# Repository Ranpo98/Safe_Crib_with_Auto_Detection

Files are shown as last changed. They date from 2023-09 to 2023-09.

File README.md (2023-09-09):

# Safe Crib With Auto Hazard-Detection

## Project Overview

**Duration**: December 2022 – May 2023

The "Safe Crib With Auto Hazard-Detection" is an innovative project aimed at utilizing technology to enhance the safety of infants while in their cribs. The project focuses on developing a system that employs various sensor arrays to monitor the baby's movements and posture in the crib, alerting caregivers to potential unintentional falls and other hazards. 

## Features and Achievements

- Utilization of various sensor arrays to closely monitor baby's movements and posture within the crib, providing alerts for unintentional falls.
- Independent PCB design, forming the central control hub for the sensor array and a Bluetooth module facilitating data transmission.
- Simulation and testing of PCB conditions with extensive sensor arrays connected, using Kicad and Cadence® Virtuoso®.
- Prototyping and real-situation sensor accuracy testing with the aid of a breadboard and a crib model crafted with machine tools.
- Implementation of Arduino IDE encoder to program the receiving PCB, and store the predetermined method for decoding transmitted bit signals.
- Nominated for a showcase during the Senior Project design and approval stage, securing a full score in the evaluation phase.

## Technologies Used

- Sensor Arrays
- Bluetooth Module
- Kicad
- Cadence® Virtuoso®
- Arduino IDE

## Repository Contents

In this repository, you will find all the files generated throughout the project's progression.

### ⚠️ License & Usage

Please note that unauthorized use of any files or code found within this repository without explicit permission is strictly prohibited.

## Getting Started

To delve deeper into the project details, navigate through the repository. Inside, you will find a rich collection of files, including but not limited to:

- Circuit Designs
- Code Files
- Sensor Calibration Data
- Prototyping Images and Videos

## Conclusion

This project stands as a testament to the fusion of technology and child safety, embodying innovation and dedication.

Thank you for visiting the "Safe Crib With Auto Hazard-Detection" project repository!

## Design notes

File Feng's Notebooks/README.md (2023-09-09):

# ECE 445 Lab Notebook

## 02/10

### Pressure and Sound Sensor 
We carefully considered various options for each subsystem and determined that our pressure sensors should withstand a maximum force of approximately 50 N. After thorough research, we ultimately chose the SEN0294 pressure sensor due to its ability to measure up to 60 N of force. Our team deliberated extensively over which sound sensor to use, as we wanted to select one with a sound pressure level threshold as close to 110 dB as possible.

## Ultrasonic Sensor 
HC-SR04 and HC-SR05 are both designed for distance measurement. However, they are a bit differ in aspects such as operating frequency, which makes the difference in accuracy and response time. Compared to HC-SR05, HC-SR04 operates at a higher frequency of 40kHz, providing higher accuracy. Additionally, HC-SR04 has a shorter response time and can complete a operating cycle in 10 microseconds, while HC-SR05 requires around 58 milliseconds. 

## 02/15

## Connection to Program the Board
I read the document of ATMega328P(https://www.farnell.com/datasheets/74880.pdf). It is wise to use SPI for programming interface. ATMega328P is an 8-bit microcontroller widely used in embedded systems. Through the SPI interface, it can communicate with other devices, such as sensors and displays. The SPI interface uses four signal lines, namely MOSI (Master Output Slave Input), MISO (Master Input Slave Output), SCK (Clock), and CS (Chip Select). In ATMega328P, MOSI and MISO correspond to the output and input data pins. Besides, SCK provides the clock signal, and CS helps select the communication device. 

## 02/17

## Connection to Program the Board (Continue)
After carefully reading the document, I determine to use the interface protocol UART, which uses two signal lines, TX (Transmit) and RX (Receive) for serial communication. In ATMega328P, TX and RX correspond to the output and input data pins. 

## 02/18

## MCU Choice + Pin Connection Check
1. How the output of the sensor be suitable for the MCU? Voltage range? Duration?
2. What are the appropriate resistor/capacitor? Tolerance range
3. What is the clock cycle to burn the code onto the board?   

## Completion progress: 
1. Used the SPI interface to program.
2. Specified the wanted PCB must have MOSI, MISO, and SCK function. ATMega328P fits our requirement. Link of datasheet: https://content.arduino.cc/assets/Atmel-7810-Automotive-Microcontrollers-ATmega328P_Datasheet.pdf
3. The operating voltage range: 2.6 V (±0.1V) to 5.4 V (±0.1V)
4. The operating frequency for ATmega328 is 8MHz, which is acceptable for this project. 

## 02/19

## Team Contract(Responsible for the primary drafting of this document)
Our team determine to keep effective communication and collaboration to maintain a good track on the project for the final success. We have set up regular meetings every Monday afternoon and plan other meetings flexibly based on our progress. During these meetings, we will discuss specific tasks and deadlines, share progress updates, and offer feedback to each other.

Moreover, we have established a public document to keep track of our schedules, tasks, and progress. This document helps us to stay organized and open to ideas and ensures that everyone is on the same page. If a member needs assistance or is facing any difficulties,  we can discuss and solve any issues together. Our goal is to work cohesively and efficiently while supporting and encouraging each other throughout the process.      

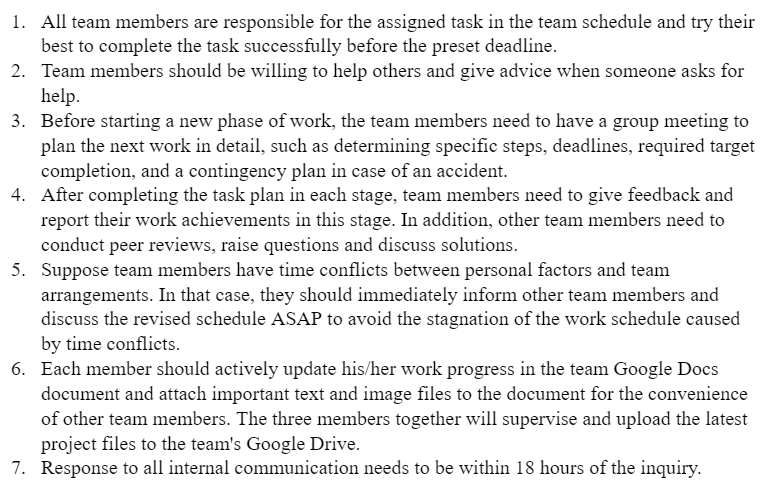
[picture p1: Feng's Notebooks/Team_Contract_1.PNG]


## 02/23

## Reading the SPI Protocol Documents
I looked over some websites and Youtube videos to learn about AVR microcontrollers and the SPI communication protocol.

1. Basic concepts of the SPI communication protocol: SPI (Serial Peripheral Interface) is a serial communication protocol used for communication between microcontrollers and external devices.
2. The master-slave device concept in SPI: The SPI communication protocol has one master device and one or more slave devices, with the master device responsible for controlling the communication process.
3. Four signal lines of SPI: MOSI (Master Out Slave In), MISO (Master In Slave Out), SCK (Serial Clock), and SS (Slave Select).
4. AVR microcontroller's SPI module: Learn how the AVR microcontroller implements SPI communication functions and understand the roles and configuration methods of its internal registers.
5. Example codes for SPI communication, including configuring SPI registers and methods for sending and receiving data.

## 02/27

## PCB Sensor Modification
I redesigned the arrangement of 15 pressure sensors on the PCB. I designed that the 15 sensors would be arranged in three rows and five columns. Within the same row, each column would be connected in parallel and then each one will also be connected in series to a resistor to ensure that there is no excessive current flow, which may cause a short circuit. Additionally, the five sensors in each row would be connected in series with an NMOS to control the switch for the pressure sensor measurement function. By doing this, we can reduce the number of analog pins required on the MCU.

(Updated on 4/26) We have considered the impact of the high-frequency switching signal caused by the NMOS on the low-frequency signal of the pressure sensor itself. However, in the actual verification process, the interference was not significant, so it is within an acceptable range.

## Tips
It should be noted that the logic of these NMOS is to read the readings of all sensors in the array at high. Therefore, the readings of five sensors in each row will be read at the same time. Therefore, it is necessary to carefully read the data in the right order to avoid recording wrong sensor data.         

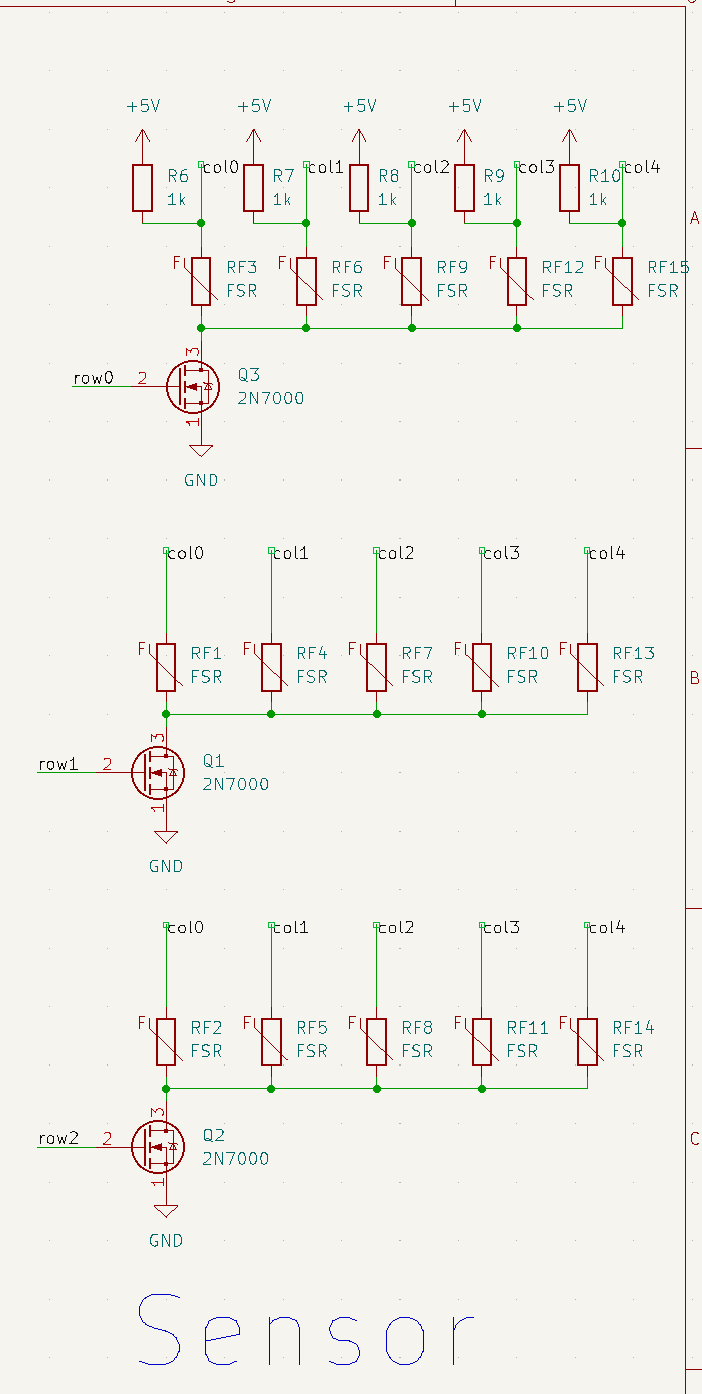
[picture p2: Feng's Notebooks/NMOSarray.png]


## 03/03

## Prototype Sensors On Breadboard (Pressure Sensor in 3*3)

This week, I received the first batch of pressure sensors and began conducting related tests on a breadboard. Since there were less than 15 sensors, I temporarily set up a small-scale test with a 3x3 grid. I connected the pressure sensors to the Arduino Uno according to the PCB schematic and attempted to apply pressure to multiple sensors simultaneously to observe the readings reflected in the Arduino IDE terminal. Meanwhile, I also started writing code for the pressure sensor data evaluation, allowing the MCU to print a preset alarm message when it detects more than 5N of force on multiple pressure sensors simultaneously. The result was that the prototype successfully achieved the desired outcome during the small-scale breadboarding test.

## 03/06

## Prototype Sensors On Breadboard (Add Ultrasonic Sensor) 
I plan to complete the Pressure Sensor, Ultrasounic Sensor, and Sound Sensor prototyping, splice the basic circuit on the breadboard, and code corresponding driver on the Arduino IDE.

For the pressure Sensor, the increase of pressure will lead to the decrease of resistance, so it is quantified as a value in the range of 1-1024 in IDE. By building a 3*5 matrix, we add judgment statements. Every time the value of a sensor in the matrix changes to a value less than 900 after each loop delay, the count increments by 1. Then, if the current count value is greater than 4, it can be used to judge that the baby is crawling. For ultrasounic Sensor, I let the program detect the difference between the two return times of echopin, multiply by the speed of the sound and divide by two to get the distance data. Finally, whether the distance is less than the length of crib is detected to determine whether the baby triggers the alarm. The sound sensor returns a voltage data, so I wrote the code to detect and calculate the difference of it between loops and match that to the range between 1-1024, the higher than volume is, the larger the value is. Once the value is higher than 58, it will set a preset variable to true and trigger the alarm.

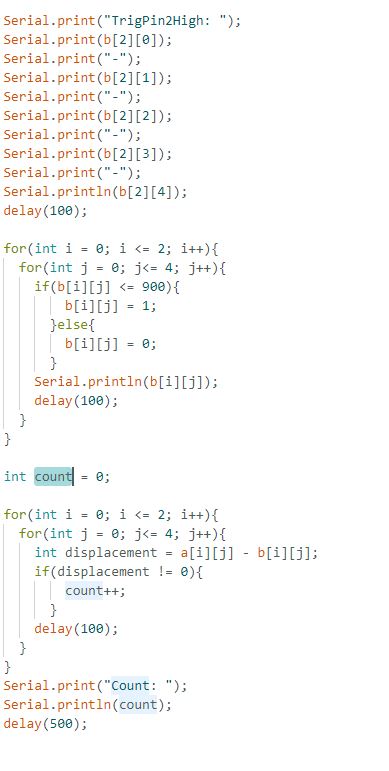
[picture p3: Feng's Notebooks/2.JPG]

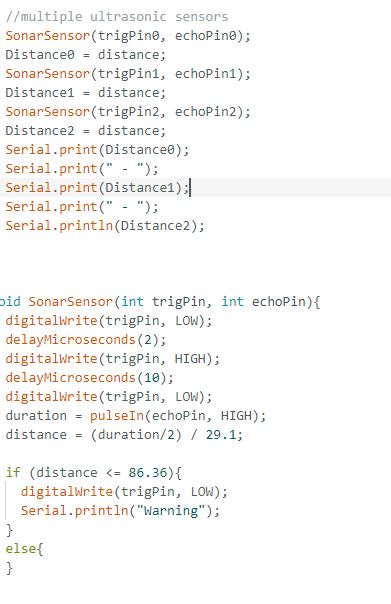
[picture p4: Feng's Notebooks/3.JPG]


## 03/13

## Preliminary Setup of the Pressure Sensor on the Breadboard
I preliminarily completed the layout and wiring of the pressure sensor on the breadboard and conducted an initial test by connecting it to the Arduino UNO. It was verified that the pressure sensor could successfully measure results. However, there were still some issues. As the individual pressure sensor was a thin sheet, its sensitivity to pressure changes was compromised due to its thinness and the pressure applied on it being dispersed by the tabletop it was on.

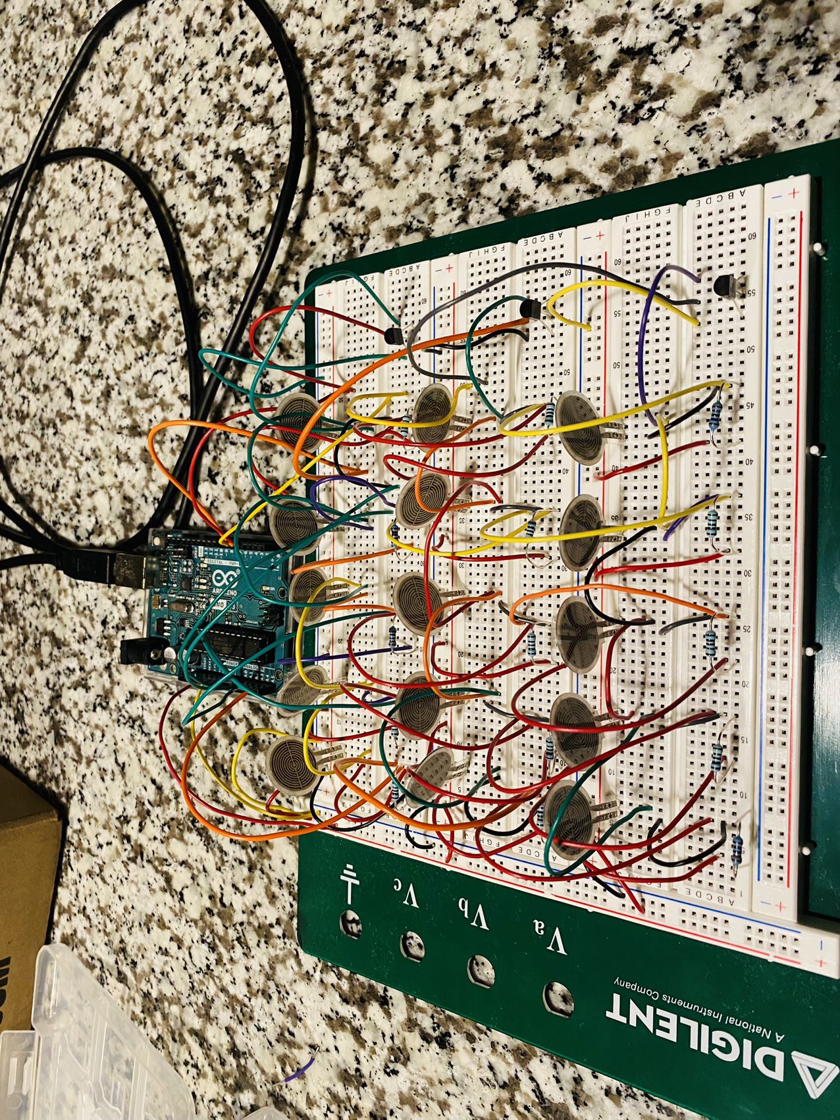
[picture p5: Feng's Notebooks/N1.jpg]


## 03/16

## Preliminary Setup of the Ultrasonic Sensor on the Breadboard
I conducted testing on the ultrasonic sensor, and it was detected that due to the HC-SR04's Effectual Angle being approximately 15 degrees, caution needs to be taken when arranging the sensors to ensure they are not too close together. Additionally, I also observed some strange phenomena, where obstruction in front of the ultrasonic sensor in position 4 would trigger an alarm in position 2. Furthermore, sometimes, the alarm trigger probability is unstable when an object is placed at the threshold distance set in the program. I believe this is due to the microphone of the sensor emitting sound waves that are too scattered.

## 03/20

## Integrate Sensors Prototype
I have started and complete partially on the integration of the Sensor Prototype. I want to test whether the program can simultaneously process the input data of multiple sensors. Also use a 3-bit array to represent all eight cases, including the trigger/not trigger cases for three sensors. It makes convenience for the data transmission through Bluetooth later in the project. 

I asked the program to output a variable for each sensor based on the trigger criteria we previously set for each sensor. If the corresponding condition is triggered, bitSet the value to 1, otherwise bitClear the value back to zero. Each sensor occupies one bit of code, so the three sensors correspond to three bits of code, which are 2\*2\*2 = 8 cases in total. Therefore, the receiving end can recognize the corresponding case after receiving the Bluetooth signal.

| Ultrasonic | Pressure | Sound | Readings |
| ---| ---| ---| ---|
| 0 | 0 | 0 | Read as case 0 |
| 1 | 0 | 0 | Read as case 1 |
| 0 | 1 | 0 | Read as case 2 |
| 1 | 1 | 0 | Read as case 3 |
| 0 | 0 | 1 | Read as case 4 |
| 1 | 0 | 1 | Read as case 5 |
| 0 | 1 | 1 | Read as case 6 | 
| 1 | 1 | 1 | Read as case 7 |

## 03/25

## Modification on Crib Model -- Large Paper Box
I made some modifications to the crib model, which is a paper box that fits the dimensions described in our design document. In order to ensure that the ultrasonic sensor array can cover all areas of the short side of the crib, I reduced the distance between the two middle sensors from 15cm to 10cm, which ensured full coverage of the scan, and duplicate areas will obtain data from two sensors that can be used to verify the data.

I cut the paper box according to the style of the baby crib, cut off the top surface, and then taped one of the openings on both sides, leaving the other opening for easy installation of the pressure sensor matrix and necessary adjustments. Then, together with Yuhao, we accurately marked the installation positions of each pressure sensor on the bottom edge of the paper box, for easy installation later. I also marked the installation positions of the subsequent circuit case and ultrasonic sensors on the outer wall of the paper box.

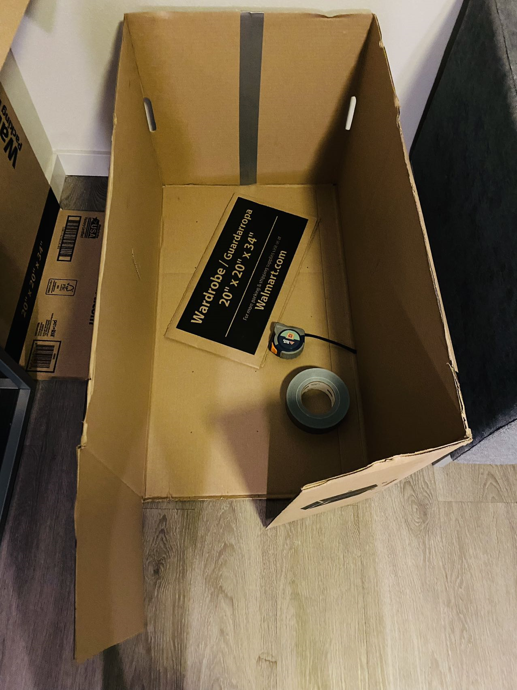
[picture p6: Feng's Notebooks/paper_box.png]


## Issue on Sound Sensor
Upon testing the sound sensor, we discovered some unexpected issues. When there is no noise in the nearby environment, the digital output continuously returns a value of "1," and the analog output returns around 60. We have identified this as a malfunction in the sensor. We may need to buy a brand-new sound sensor or adjust the if statement in the code. 

## 03/28

## Installation of Pressure Sensor & Crib Surface Polishing  
Since Dushyant did not know we had two PCBs, the timing of the order was delayed. As a result, we cannot perform soldering on the crib PCB at this stage. Therefore, I decided to start building our crib model, which is the cardboard box previously mentioned. To address the sensitivity issue with the pressure sensor mentioned before, and combining with Xinlong's idea, we obtained 15 cylindrical pieces of wood from the machine shop, each with a height of 10mm, a diameter of 16mm, and a total weight-bearing capacity of at least 6.8Kg. I attached these cylindrical pieces to the plastic film surface of the pressure sensor with double-sided tape, making them at a different height level from the crib's bottom cardboard. Therefore, the force applied on the objects above would be mainly concentrated on the plane of the cylindrical pieces, thereby transmitting the force to the pressure sensor and enhancing its sensitivity during actual operation. I plan to complete the bottom wiring and the wooden cylinder attachement of the pressure sensor within four days, as well as cut the box to make it closer to the shape of a real crib. Additionally, I adjusted the installation position of the ultrasonic sensor, added a back panel for fixing, and polished and adjusted the cardboard on both sides to ensure that there are no overly uneven parts.

As we are still testing the ultrasonic sensor on the breadboard and Xinlong wants to use this opportunity to test the monitor subsystem, I plan to install the remaining two types of sensors onto the crib in one week.

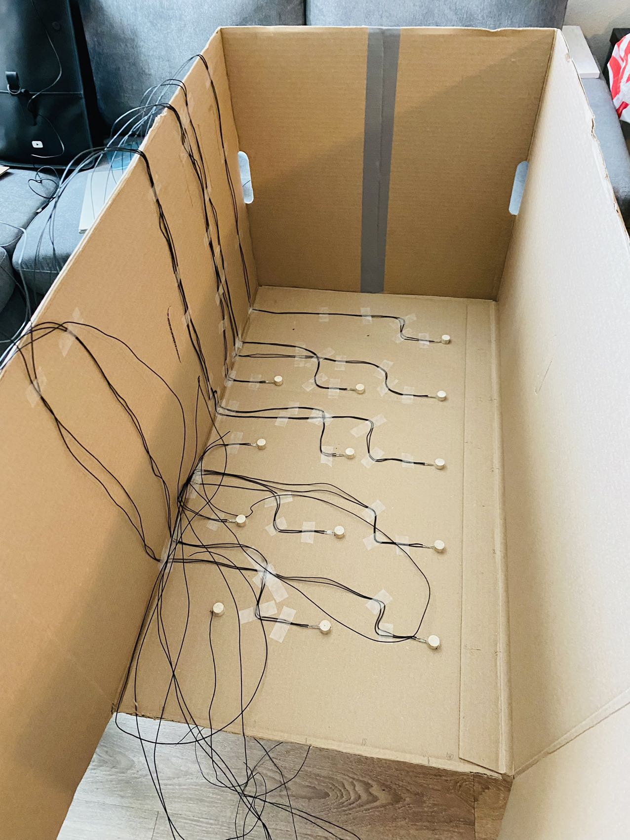
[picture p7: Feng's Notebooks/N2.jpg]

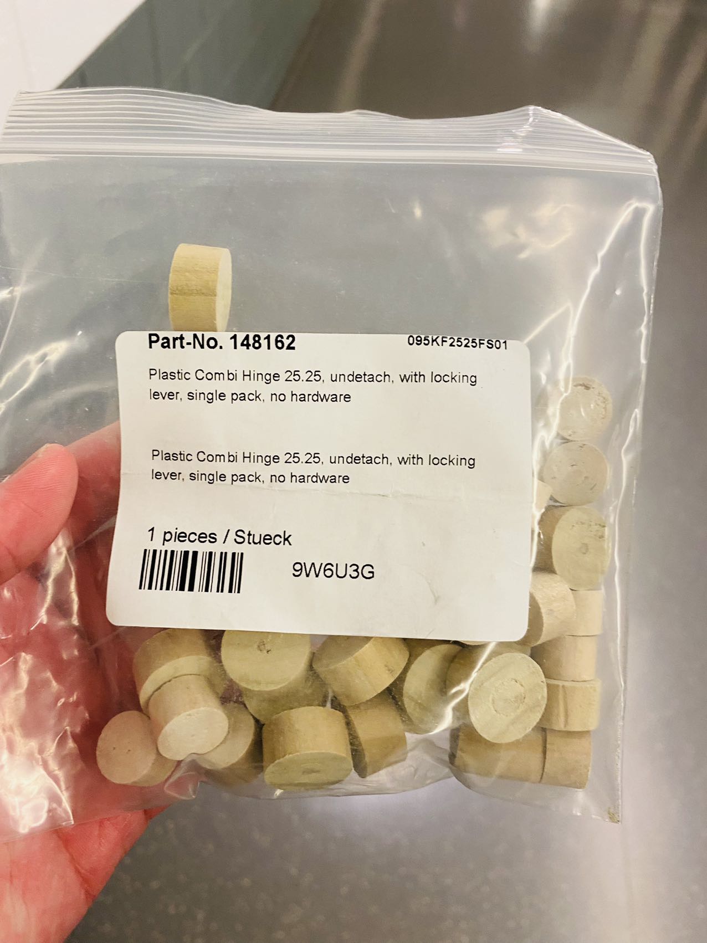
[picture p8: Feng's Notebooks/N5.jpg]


## 04/03

## Modification and Testing on the Bluetooth Data Transmission
After setting up all of the sensors, we performed a Bluetooth connection and communication test to confirm that the system could effectively collect and analyze data, and transmit information via Bluetooth. Following Xinlong's recommendation, we attempted to have the MCU and Bluetooth module send signals, containing a single letter from A to Z in each loop, transmitted in order. All of the packages were ultimately received successfully. Next, the two systems were tested by transmitting the analyzed byte information to the receiving end, where it was successfully printed on the display. We also tested the triggering of each sensor and arranged them in various combinations, with most combinations successfully displaying the corresponding text on the receiving end and triggering the corresponding buzzer.

However, it should be noted that during our testing of the pressure sensor, its performance was slightly subpar. The display often did not show any text, indicating that the alarm was either not sent via Bluetooth or was not triggered due to a mismatch in communication refresh cycles between the two systems. We reduced some of the delays and the threshold of the pressure sensor in the program, which resulted in a slight improvement, but further improvement is still needed.

## Not Showing "Crib signal not found" on Display
We have rectified a software glitch that prevented the "Crib signal not found" notification from appearing on the screen when there was no signal received from the Bluetooth. This issue is caused by an AND operation (avail_num == 0 && cur_time > last_msg_time + WAIT_MSG_TIME_OUT) in the code. It makes legal action to skip the return statement in the loop. These are the detailed explanantion: 

1. avail_num == 0: This condition checks if the number of available signals (avail_num) is equal to 0. A value of 0 indicates that no signal is being received.
2. cur_time > last_msg_time + WAIT_MSG_TIME_OUT: This condition checks if the current time (cur_time) is greater than the last time a message was received (last_msg_time) plus a predefined waiting timeout duration (WAIT_MSG_TIME_OUT). If the current time exceeds this calculated limit, it means that the maximum allowed time for waiting for a message has been surpassed.

The conditional expression uses a logical AND operator (&&), which requires both conditions to be satisfied in order to return true. If avail_num is 0 (no signal) and the current time has exceeded the allowed waiting time limit, the expression evaluates to true. This typically triggers a subsequent action, such as, in this context, causing the "Crib signal not found" notification to not be displayed when the expression is true. We changed the second statement scope to the subordinary scope of the first statement to fix this issue. 

## Inconsistencies in Pressure Sensor Performance
The pressure sensors are supposed to consistently deliver notifications indicating the baby's movements when any of them detects a change within a certain range. However, in some instances, notifications were triggered during both pressing down and release, while in others, they were only activated during one of the action, not both. There are even cases that no notifications were generated at all, which is in nearly 5% of the time. We initially attempted to rectify the issue by comparing the time difference between two readings, but this approach does not improve much. Likewise, averaging ten readings into a single measurement to avoid interference did not work well. Upon more detailed testing and analyzing, we decided not to care too much on this because the pressure sensor itself works and responds very fast and senstitive to the force change. Approximately 90% of the time, the pressure sensors provide accurate measurement data in a timely manner. 

## 04/06

## All Sensors Extended Lines Soldering
Xinlong and I went to 2070 to perform soldering on the pressure sensor and ultrasonic sensor since the preliminary testing on the breadboard was completed. We needed to add extension wires to connect the sensors to the PCB boxes installed on the cardboard box's sidewall. During the soldering process, we encountered a problem where the pin of the pressure sensor was very thin, resulting in hollow soldering points that would automatically come off after a while. We had to perform additional soldering a few times to fix this issue.

## 04/08

## Crib Physical Structure Build-up
The crib has been built and is considered mostly completed, with all three sets of sensors successfully installed. The pressure sensor is installed at the bottom of the cardboard box, with a layer of plastic film covering it to prevent any risk of electrical shock. On top of the sensor is a layer of mattress. The ultrasonic sensor is first installed on a piece of cardboard, then attached to the short side of the crib with adhesive, ensuring that the sensor is at a height of about 20 inches from the bottom. However, the sound sensor has not been installed yet since it needs to be installed in the crib's PCB box, which has not arrived from the machine shop yet.

I organized and routed the long wires of the pressure sensors according to my pre-planned layout, and then managed the wiring on the side walls of the crib cardboard box. Finally, I bundled the wires on the exterior of the longer side wall. Xinlong mentioned that he wanted to be responsible for connecting the wires to the PCB pins, so I handed that part over to him.

## 04/15

## Ultrasonic Sensor Issue
After installing the four ultrasonic sensors on the crib, we conducted tests on them. However, the results of this on-site test on the crib differed significantly from our previous tests on the breadboard. In simple terms, the sensors became extremely unstable. Sometimes they would trigger an alarm beyond the preset warning distance, while other times they remained unresponsive even when touching the microphone surface. We studied the issue for a long time, adjusted the code parameters, but it does not change its performance much. 

Eventually, we discovered that the ultrasonic sensors on the edges sometimes alarmed for objects placed outside the crib, which meant that the detection range of the ultrasonic waves was broader than we had imagined. A reasonable hypothesis was that the width and length of the microphone surface caused the ultrasonic waves to emit not from a single point, making the sound waves spread wider as they traveled, eventually reflecting off objects outside the originally anticipated range, causing detection errors and false alarms.

To address this issue, we devised a targeted solution. We cut A4 paper into strips, rolled them into tubes, and fitted them onto the ultrasonic sensors, allowing the sound waves emitted from the microphone to propagate through an extended channel. This measure effectively enhanced the directionality of the sound waves, significantly reducing the edge sound wave reflections influenced by surrounding objects, and consequently reducing false alarms and non-alarm occurrences.   

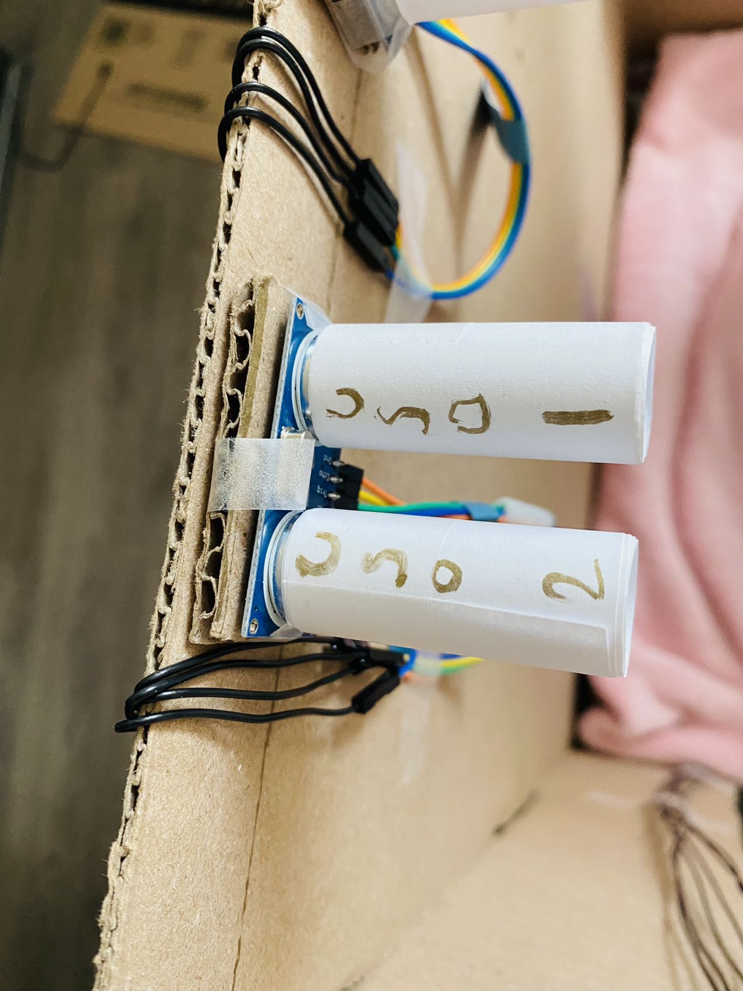
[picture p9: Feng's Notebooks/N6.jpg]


## 04/17

## Ultrasonic Sensor Issue (Continue)
After several days of thinking, I proposed an alternative plan. Since we consider that the measurement errors were caused by the diffusion of ultrasonic waves and the cluttered reflections from the crib's four walls, we could install sound-absorbing materials on the two long sides and one short side to prevent the generation of scattered waves. Ultimately, we purchased dishwashing sponge cloths from the supermarket and placed them on the cardboard walls on all four sides. Due to the abundance of wires on the two long sides, we temporarily decided to apply the sponge cloths only to the opposite short side cardboard wall. The latest results showed an improvement in the performance of the ultrasonic sensors, eliminating most of the previous false alarms and non-alarm occurrences.

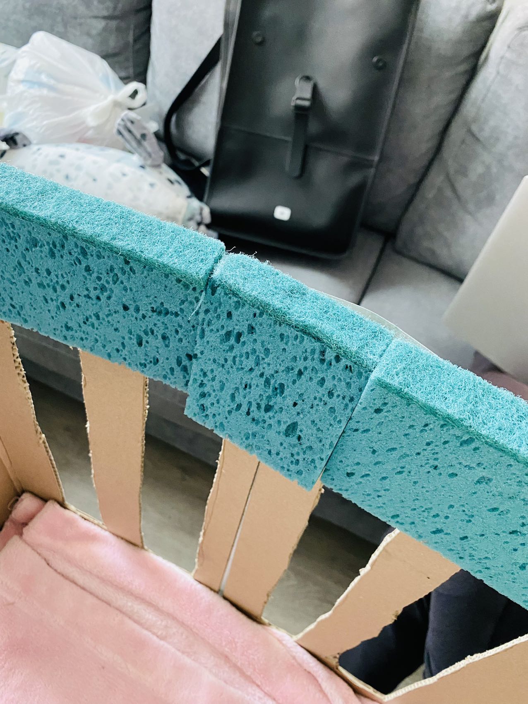
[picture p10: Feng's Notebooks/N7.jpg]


## 04/22

## Ultrasonic Sensor Issue Reason -- Crosstalk?

During this process, we reflected on and recalled our previous experiments: When tested on the breadboard, the ultrasonic sensors worked perfectly fine, so we never anticipated any issues with this part in the crib model. Therefore, to identify the root cause of the problem, we must thoroughly analyze the differences between the breadboard and PCB environments to determine any critical factors that led to the issue.

The circuit board traces and clock speed were the most notable differences between testing on breadboard and in crib environment. Therefore, the can be a reasonable explanation to the ultrasonic sensor issue. One reason could be trace crosstalk between the data traces of US0 and 1. As we looked at the PCB layout, we think the crosstalk might even occur between the NMOS gate traces and US0,1,and 2, which means the pressure sensor is having some impact on the ultrasonic sensors. Although the signal sent out from the pressure sensor is low-frequency based. The high-frequency switching between high and low states of NMOS could create interference with other high and low-frequency signals. This problem was not observed or was rarely seen on the breadboard prototype because the development board is made by industrailized standard and the traces implemented were well-organized and nearly no crosstalk.

As I mentioned before on 03/28, the delay in ordering the PCB cost us two weeks that could have been used for debugging the PCB design. If we were to make any corrections in the next step, we might start by reconfiguring the PCB layout with a more reasonable wiring arrangement.

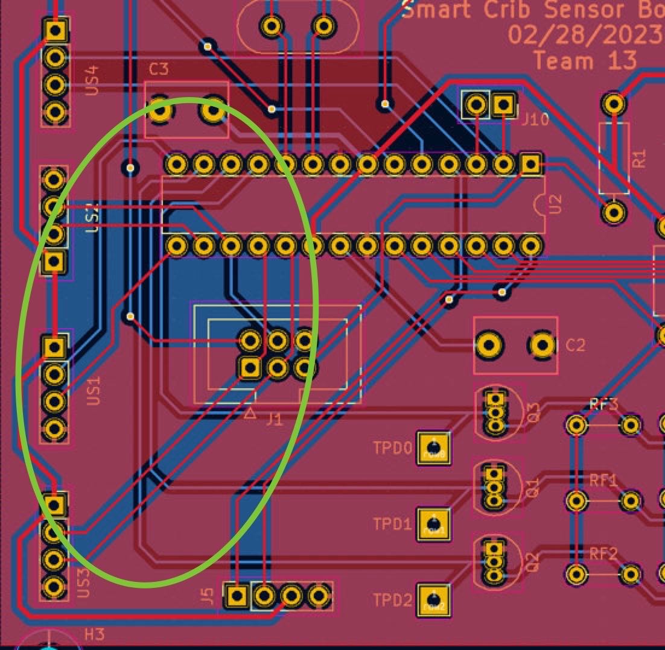
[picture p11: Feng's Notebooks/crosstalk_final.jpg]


## 04/25

## Final R/V Checkout
Before our upcoming demo, we conducted the final full-system R/V checkout. Here is a summary of the R/V of our Crib Subsystem.
The following text refers to "alarms" as displaying corresponding text information on the screen and the buzzer emitting a beep sound.

1. R: The ultrasonic sensor should inform the MCU if the baby reaches a height of 20 in ± 0.5 in from the bottom of the crib. 
   V: We have tested this by placing our hand at the mentioned height to check if the alarm is triggered.

2. R: The sound sensor should correctly report to the MCU when there is a sound above 86 dB measured at 34 in ± 1 in from the sensor. 
   V: We have verified this by placing a decibel meter and a sound source next to the sensor and checking if the monitor would trigger an alarm when the sound source plays a sound above 86 dB.

3. R: The pressure sensor array should correctly detect the change in the number and positions of the 15 pressure sensors that feel a perpendicular force greater than 5 N. 
   V: We have tested this by applying at least 5 N of pressure to each sensor and checking if the alarm is triggered during the process.

4. R:The microcontroller can process data from all sensors and generate informational data about the safety status in the crib at all times. 
   V: During the verification process of the first three steps, the alarms were triggered correctly. The triggering timing matched our settings, i.e., the sound sensor would alarm only after continuously receiving high volume for more than 2 seconds, while the pressure sensor would alarm only after detecting data that was different from the pressure readings 2 seconds ago. This duration helps avoid false alarms.

5. R: The microcontroller can deliver informational data to another device with its Bluetooth within 10 m and with at most three 11.4 cm or thicker walls in between. The time it takes to send the data should be within 3 seconds. 
   V: Throughout the test, we placed the monitor at least 10 m away from the crib and conducted tests with the monitor at the entrance of the suite and the crib in the innermost room.

## 04/26 

## Final Demo
Today, which is Monday, we completed our final demo and successfully met all of our high-level requirements. This is certainly worth celebrating, although it was expected. Unfortunately, we had to use a breadboard to demonstrate our ultrasonic sensors because a pin related to the sensor was burnt out on the PCB. To provide a complete record, here are all the high-level requirements:

1. Detect if the baby is about to climb out of the crib
2. Detect if the baby's crying sound exceeds a threshold of 86 dB and lasts for more than 2 seconds
3. Reliable communication must be established between the crib and the monitor. Specifically, the monitor can receive safety status messages from the sensor within 3 seconds when it is within 10 meters and 3 interior walls from the crib.

## Reference
[1] J. S. Allen, "What is the average penis size?," Medical News Today, Aug. 14, 2019. [Online]. Available: https://www.medicalnewstoday.com/articles/324728#average-lengths. [Accessed: February 3, 2023].

[2] "Ultrasonic Sensor HC-SR04 with Arduino," ElementzOnline, Oct. 12, 2017. [Online]. Available: https://www.elementzonline.com/blog/ultrasonic-sensor-hc-sr04-with-arduino. [Accessed: February 10, 2023].

[3] S. Williams, "Understanding the Basics of Ultrasonic Proximity Sensors," All About Circuits, Feb. 24, 2021. [Online]. Available: https://www.allaboutcircuits.com/industry-articles/understanding-the-basics-of-ultrasonic-proximity-sensors/. [Accessed: February 13, 2023].

[4] Atmel Corporation, "Automotive Microcontrollers ATmega328P Datasheet," 2015. [Online]. Available: https://content.arduino.cc/assets/Atmel-7810-Automotive-Microcontrollers-ATmega328P_Datasheet.pdf. [Accessed: February 15, 2023].

[5] R. H. James, "SPI Master/Slave Connections Between ATmega328P's," RJH Coding, Apr. 22, 2012. [Online]. Available: http://www.rjhcoding.com/avrc-spi.php. [Accessed: February 23, 2023].

[6] D. Stojanovic, "How to Configure and Pair Two HC-05 Bluetooth Module as Master-Slave Commands," HowToMechatronics, Dec. 22, 2016. [Online]. Available: https://howtomechatronics.com/tutorials/arduino/how-to-configure-pair-two-hc-05-bluetooth-module-master-slave-commands/. [Accessed: March 25, 2023].

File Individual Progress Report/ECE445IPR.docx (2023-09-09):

# ECE445

Individual Progress Report Yuhao Yuan

Spring 2023

# Introduction

In this project, I mainly work on investigating the power subsystem and the control subsystem. The crib power subsystem offers a constant power supply to the entire crib PCB. And the crib control subsystem aids the system to receive data from the other sensors, processing them, and send the corresponding message to the receiver end.

Besides, I’m also responsible for the entire crib PCB design.

# Design & Verification

## Crib Control Subsystem

The main components of the crib control subsystem are the microcontroller and the Bluetooth module. These two components work together to monitor and control the functions of the baby crib.

The microcontroller is responsible for performing various functions, including collecting and analyzing data from sensors. It uses ultrasonic sensors to obtain distance measurements, pressure sensors to gather analog voltage output, and digital and analog pins to confirm sound detection through a TTL pulse. By analyzing these measurements, the microcontroller can determine if the baby is crying or trying to climb the guardrail of the crib. Additionally, the analog outputs from the pressure sensors are converted into integers through the Analog-to-Digital Converter. Once the microcontroller has determined the baby's state, it sends a message to the monitor subsystem to update the display and trigger alarms.

To facilitate the communication between the crib and the monitor subsystem, a Bluetooth module is used. This module is connected to the digital pinout of the microcontroller and sends messages regarding the baby's current state, such as whether they are crying or trying to climb the guardrail, to the monitor control subsystem. The monitor control subsystem receives these messages and implements the corresponding display and alarm, ensuring that the baby is safe and monitored at all times. With the Bluetooth module in place, the monitor subsystem can be updated in real-time, giving parents peace of mind that their child is being carefully watched and protected.

For our purpose, we have four ultrasonic sensors, which occupy eight digital pins. We also have a pressure sensor matrix, which requires five analog pins. Lastly, we have a Bluetooth module and a sound detector, which require two digital pins and one analog pin separately. However, this pin assignment is still tolerable under the choice of ATmega328p.

Other than the pins from sensors and communication, I also implemented a few designs on the MCU programming. I added a USBASP port such that the

microcontroller is programmable and a 16MHz crystal oscillator to serve as the MCU clock generation.

Investigating the Microprocessor

We need to choose the appropriate MCU for our control subsystem. Since we plan to prototype everything on the breadboard with the Arduino Uno development board, the microprocessor ATmega328p is a decent choice. Therefore, I did some research about this MCU to see if it can tolerate those pin assignments.

The ATmega328P microcontroller has a total of 28 pins, each with a specific function that can be configured by the user. These pins are arranged in two rows, with 14 pins in each row. The pin assignments for the ATmega328P microcontroller are as follows[2]:

- Pins 1 and 2: These are the crystal oscillator pins, used to connect an external oscillator for clock generation.
- Pins 3 and 4: These are the reset pins, used to reset the microcontroller.
- Pins 5 to 12: These are the digital input/output pins, numbered 0 to 7 respectively.
- Pin 13: This is a special digital output pin that is connected to an LED on many development boards.
- Pins 14 to 19: These are analog input pins, also used for digital input/output functions.
- Pins 20 and 22: These are the ground pins.
- Pins 21 and 27: These are the voltage supply pins. Pin 21 is connected to VCC, which is typically 5V, while pin 27 is connected to AVCC, which is the supply voltage for the analog-to-digital converter (ADC).
- Pins 23 to 26: These are the digital input/output pins, numbered 8 to 11 respectively.
- Pin 28: This is the analog comparator output pin.

By configuring these pins, we can control various functions of the microcontroller, such as reading sensor inputs, controlling motors, and communicating with other devices.

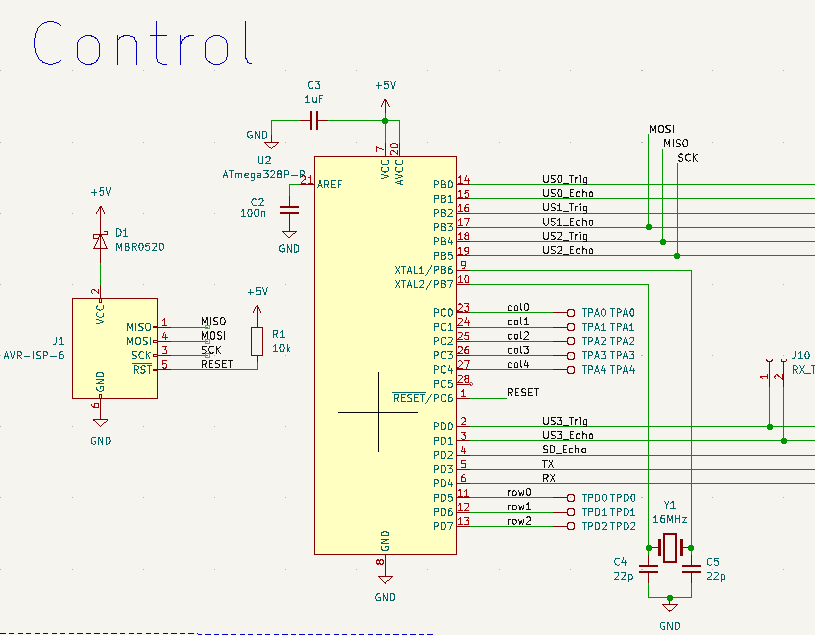
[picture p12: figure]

Figure 1. Crib Control Subsystem without Bluetooth Module Schematic

Researching Bluetooth Module

Since our project will include pairing two Bluetooth modules, it requires a Bluetooth module that can be set to the master mode. In this case, the HC-05 Bluetooth module is chosen.

There are two operating modes for the HC-05 Bluetooth module.

1. Data mode: In this mode, HC-05 sends and receives data based on Bluetooth protocols through the ports defined as Serial pins.
2. ATCommand mode: HC-05 stops transmitting data and is ready for configuration from ATCommands.

The following figure shows the interfacing of the HC-05 Bluetooth module. As the figure depicts, I only need four of these pins:

1. Vcc pin(connect to 5 V)
2. GND pin(connect to 0 V)
3. RX(connect to Arduino UNO TX pin)
4. TX(connect to Arduino UNO RX pin)

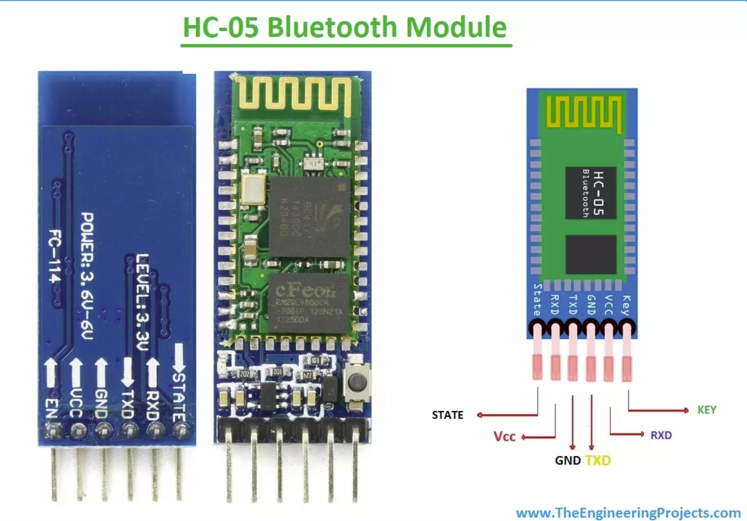
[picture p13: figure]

Figure 2. HC-05 Bluetooth Module Pin Assignments

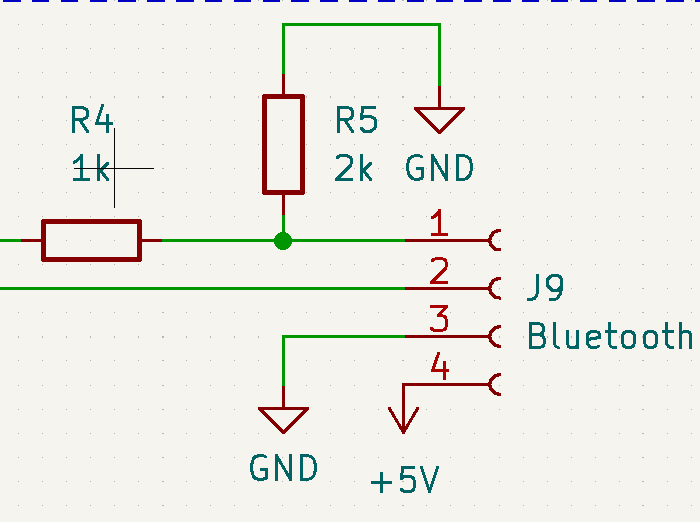
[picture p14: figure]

It is also important to note that the RX pin of the HC-05 requires a maximum 3.3 V voltage instead of 5 V. To achieve this, I applied a voltage divider such that the voltage swing at the RX port is between 0 to 3.3 V.

Figure 3. Crib Control Subsystem Bluetooth Module Schematic

To physically pair two HC-05 Bluetooth modules, we need to set both devices into the ATCommand mode. What I did is first power off the HC-05, press and hold the button on the module, and re-connect the power. The device then enters the ATCommand mode and is ready for configuration. Then I set up the following commands on the slave and master devices, separately [3]:

Slave Device

1. “AT+ROLE=0” sets the device itself to become slave mode.
2. “AT+ADDR?” gets the address of the slave Bluetooth module. Master Device
3. “AT+ROLE=1” sets the device itself to become master mode.
4. “AT+CMODE = 1” sets the address of the slave Bluetooth module.
5. “AT+BIND = Address of the slave Bluetooth module”.

After these procedures, I re-connected these modules to power. The LEDs on the Bluetooth modules shine around once per two seconds, indicating that they have successfully paired.

Regarding the verification, I have already configured our Bluetooth modules through Arduino. Using the Arduino Uno development boards, we can successfully transmit and receive the data. But the data must be sent out in the format of an ASCII value, and the receiver end decodes that ASCII value and can print out its corresponding character.

## Power Subsystem

The subsystem is responsible for supplying electricity to the crib PCB board. The board includes a battery source that produces 9 volts and has a capacity of 1300 milliampere-hour, along with a linear voltage regulator. The regulator is used to convert the 9 volts into 5 volts, which is achieved by following a specific formula as stated in reference [4].

V

OUT

R

= 1. 25 V × (1 + 2 )

R

1

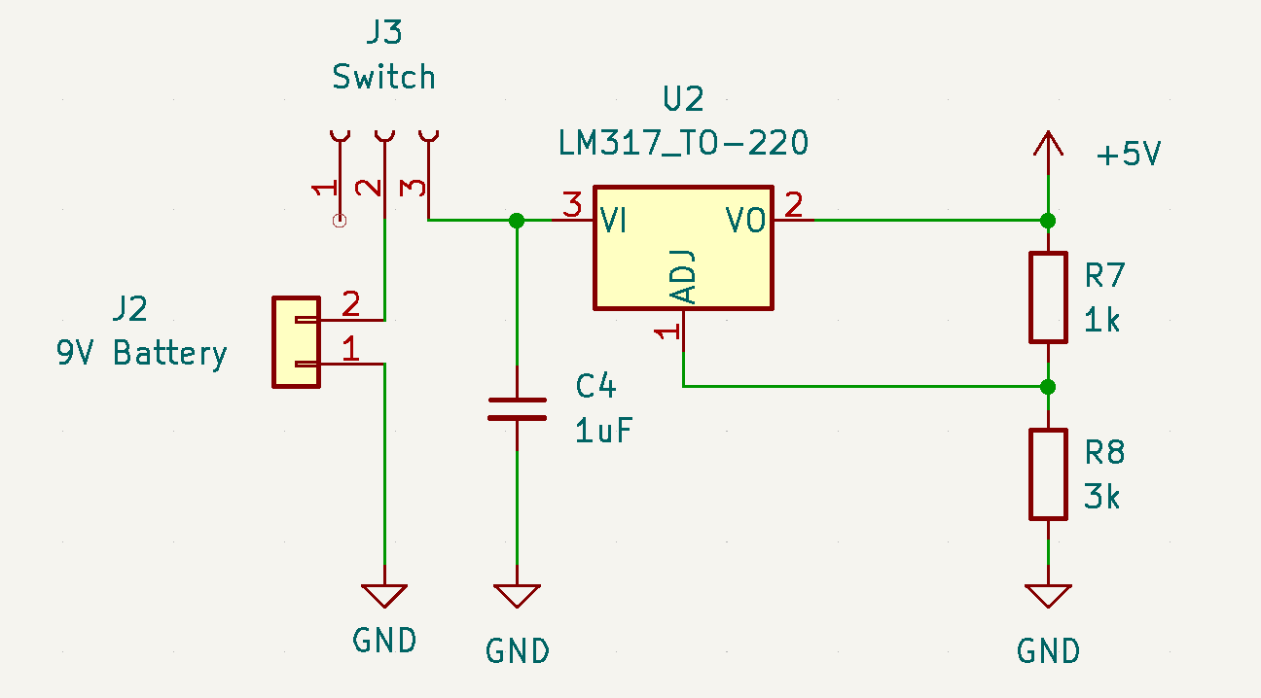
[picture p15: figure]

To ensure that the sensors and MCU receive a 5 V power supply, we select values for R2 and R1 in a way that maintains a proportion of three, resulting in a 5 V output voltage. These components make up the majority of the power requirements for the system. A switch is inserted between the voltage regulator input and the battery such that it can be electronically turned on and off.

Figure 4. Crib Power Subsystem Circuit Schematic

We’ve brought the components to the ECEB 2070 to test the voltage regulator. It turns out that if we keep the R1 and R2 at the same ratio as 3, the output voltage supply will be 4.9V, which is approximately near the 5 V supply voltage.

## Crib PCB Design

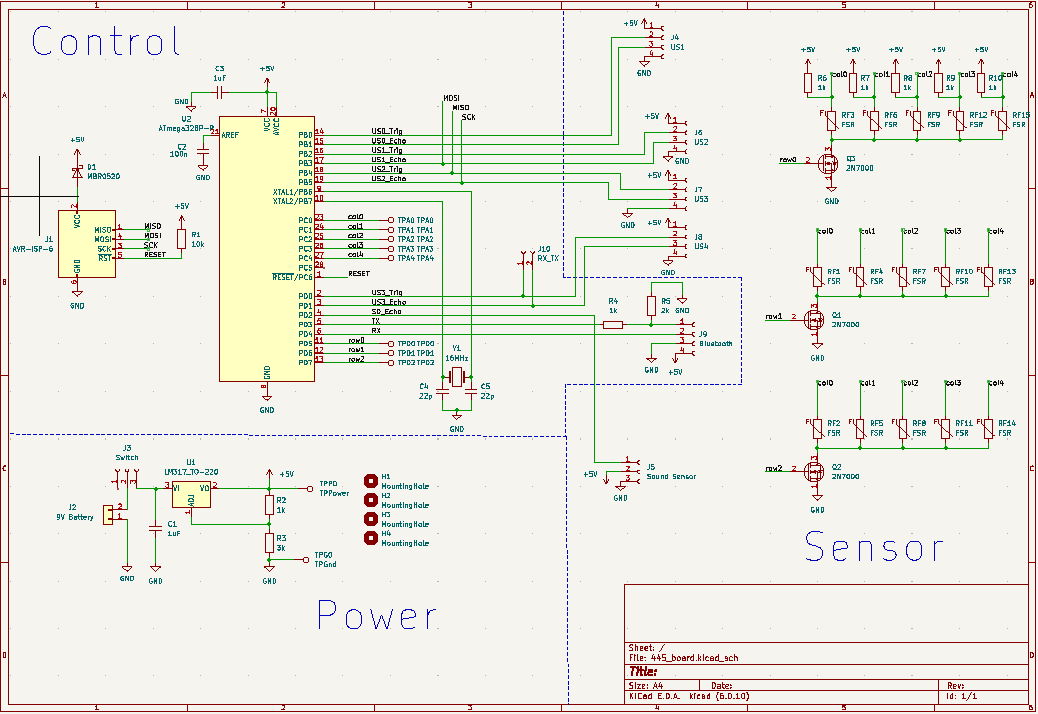
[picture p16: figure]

I am in charge of designing the entire crib PCB. It contains a Bluetooth module, a sound detector, 15 pressure sensors, and four ultrasonic sensors. Since the PCB width limit is only 10 mm, I need to manage the area wisely. Also, preventing air wiring and keeping the distance between through-hole components and wires are significant since improper soldering will short the circuit. The following figures are my designed crib PCB schematic and layout.

Figure 5. Crib PCB Circuit Schematic

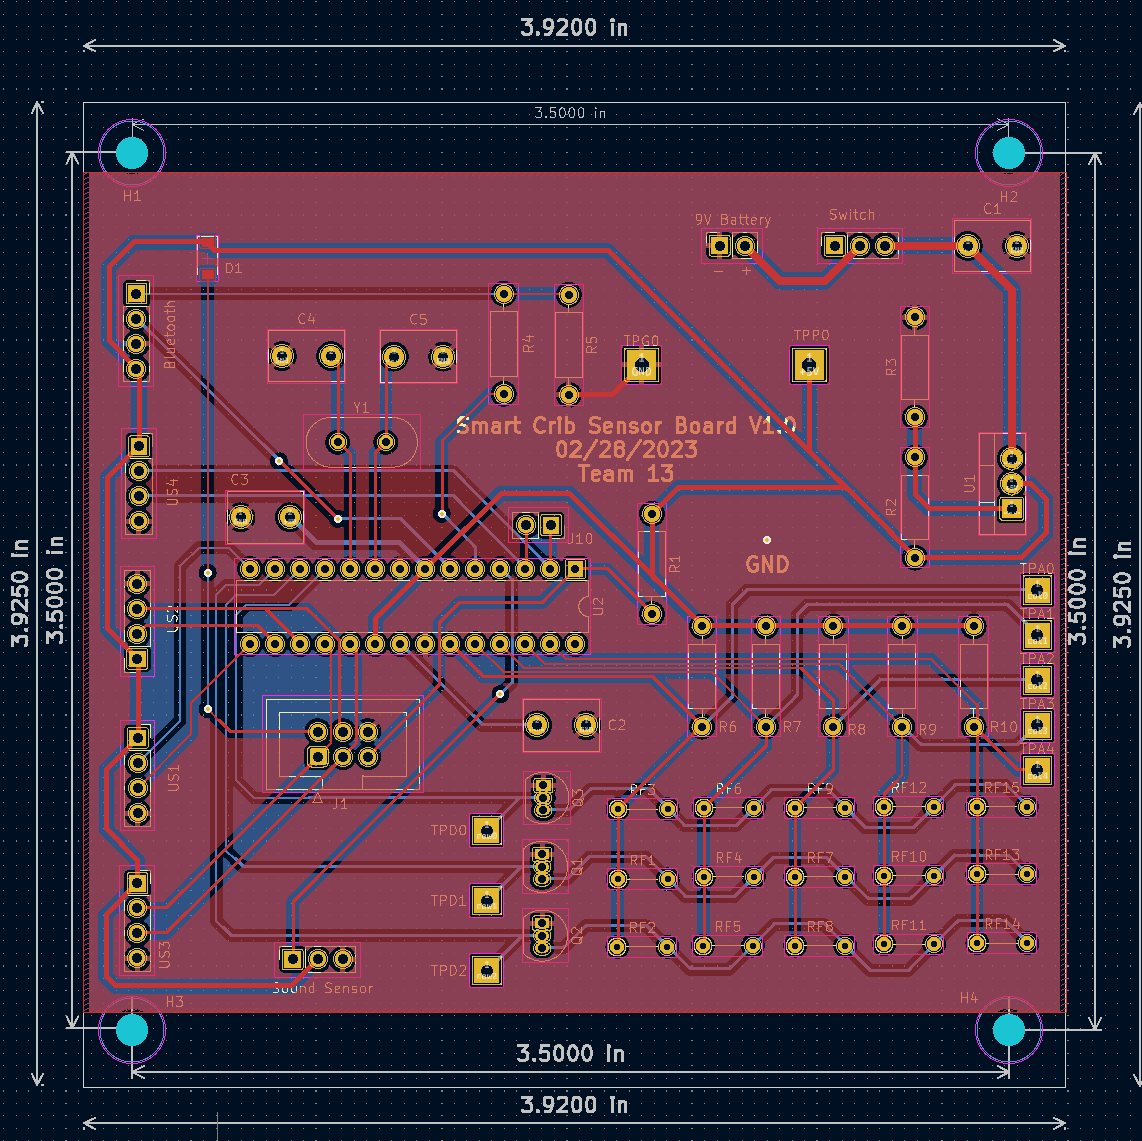
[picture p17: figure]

Figure 6. Crib PCB Circuit Layout

# Conclusion

Regarding future planning, I will still be in charge of fixing bugs in my designed PCBs if issues are encountered and re-submit them for fabrication if necessary. Since our team will integrate everything, I will also solder the parts I’ve designed. The following form is the timeline for completing my responsibilities and our project.

3/26-4/1 | Fix bugs and reorder the PCB if necessary and solder crib control and power subsystems on my designed PCB.
4/2-4/8 | Verify the entire hardware in the designed PCB.
4/9-4/15 | Continuing verifying the hardware if necessary. Integrate all the subsystems together, and prepare for the mock demo
4/16-4/22 | Revise the project in detail if necessary and work on preparing the final demo
4/23-4/29 | Work on the final report

Table 1. Timeline for Project Completion

As an ethical reminder, I am consistently and will continue to help other team members on their responsibilities if issues arise and they cannot figure them out themselves.

# Reference

[1]“ATMEGA328P - Microchip Technology.” [Online]. Available: https://www.microchip.com/en-us/product/ATMEGA328P. [Accessed: 28-Mar-2023].

[2]-Website Author Syed Zain Nasir syedzainnasir I am Syed Zain Nasir, shayantikadhar Says: and kodjo Says: “HC-05 Bluetooth module pinout, Datasheet, features & applications,” The Engineering Projects, 22-Jun-2021. [Online]. Available: https://www.theengineeringprojects.com/2019/10/hc-05-bluetooth-module-pinout-data sheet-features-applications.html. [Accessed: 28-Mar-2023].

[3]-Website Author Syed Zain Nasir syedzainnasir I am Syed Zain Nasir, shayantikadhar Says: and kodjo Says: “HC-05 Bluetooth module pinout, Datasheet, features & applications,” The Engineering Projects, 22-Jun-2021. [Online]. Available: https://www.theengineeringprojects.com/2019/10/hc-05-bluetooth-module-pinout-data sheet-features-applications.html. [Accessed: 28-Mar-2023].

[4] "LM317 3-Terminal Adjustable Regulator," [Online]. Available: https://www.ti.com/lit/ds/symlink/lm317.pdf?ts=1666119013015&ref_url=https%253 A%252F%252Fwww. google.com%252F

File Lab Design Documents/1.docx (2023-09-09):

Hi Professor Fliflet,

I went back through the literature and found that most cribs are designed for babies before age two. Federal crib regulations have set the minimum distance between the top of the mattress support and the top of the crib side rail as 26 in., and this height must include a 6-inch thick mattress. So when a mattress is used with the crib, the height of the crib side as a barrier is 20. By age two, a typical body length has reached 33.5 inches (85 cm). According to the data online: https://www.medicalnewstoday.com/articles/324728#average-lengths, even if is a 7-month-old baby, the average body length reaches 27 inches (69 cm). This means that even if you don't have a mattress, the crib fence is lower than the baby's standing height, so people can't rule out the risk of the baby climbing out of the fence.

Secondly, to answer the first question, since babies are generally more likely to cry and wake up hungry at night, it is more difficult to obtain accurate information with cameras at night. Night vision devices are more expensive, which will increase the cost significantly. At the same time, we do not need clear image information, but whether there is a baby over the fence behavior detection. Therefore, compared with the need for high-precision image recognition and simple ultrasonic detection, I think the latter is more convenient and low-cost. The possibility of error is also less than the former, which means less ineffective bother for parents.

Regarding whether ultrasound will affect the baby, we can use low-frequency ultrasound (0.1-15 MHz), which is called non-destructive testing (NDT). In our daily lives, we also use this technology in hospital ultrasounds, most of which are medical ultrasounds for pregnant women and babies. Therefore, I believe that as long as we control the ultrasonic transmission pattern well, such as low-frequency pulse emission every five seconds, it is enough to meet the daily monitoring needs and will not expose babies to the risk of ultrasonic irradiation for a long time.

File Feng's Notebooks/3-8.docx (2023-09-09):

This week, I set up the array of 34 in the breadboard, and I wrote the required code and tests in the arduino ide, and eventually completed the primary setup of prototype, but since I started with the circuit of the two breadboards, the overall volume was too large, so I was going to refactor the circuit and compress them into a breadboard. And the next thing I'm going to do, is to write a code that allows MCU to analyze the Numbers that are sent back from each sensor, and coordinate several cases to determine the baby's posture.

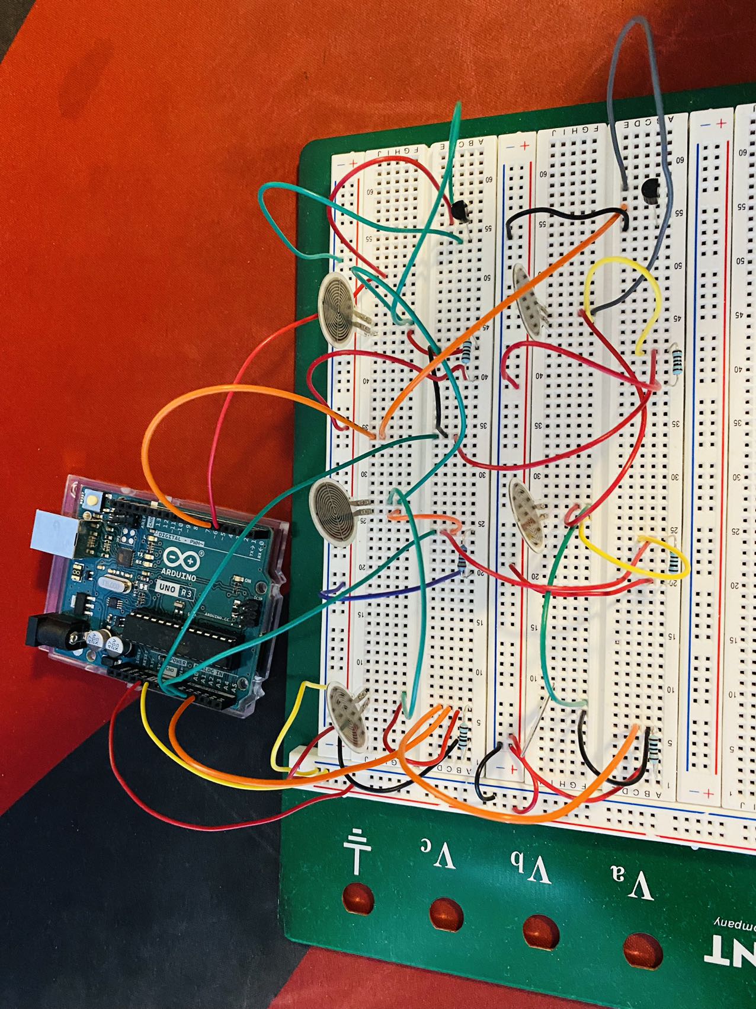
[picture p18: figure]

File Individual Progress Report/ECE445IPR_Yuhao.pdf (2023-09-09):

# ECE445

## Individual Progress Report Yuhao Yuan Spring 2023

### Introduction

In this project, I mainly work on investigating the power subsystem and the control subsystem. The crib power subsystem offers a constant power supply to the entire crib PCB. And the crib control subsystem aids the system to receive data from the other sensors, processing them, and send the corresponding message to the receiver end. Besides, I’m also responsible for the entire crib PCB design.

### Design & Verification

Crib Control Subsystem
The main components of the crib control subsystem are the microcontroller and the Bluetooth module. These two components work together to monitor and control the functions of the baby crib.

The microcontroller is responsible for performing various functions, including collecting and analyzing data from sensors. It uses ultrasonic sensors to obtain distance measurements, pressure sensors to gather analog voltage output, and digital and analog pins to confirm sound detection through a TTL pulse. By analyzing these measurements, the microcontroller can determine if the baby is crying or trying to climb the guardrail of the crib. Additionally, the analog outputs from the pressure sensors are converted into integers through the Analog-to-Digital Converter. Once the microcontroller has determined the baby's state, it sends a message to the monitor subsystem to update the display and trigger alarms.

To facilitate the communication between the crib and the monitor subsystem, a Bluetooth module is used. This module is connected to the digital pinout of the microcontroller and sends messages regarding the baby's current state, such as whether they are crying or trying to climb the guardrail, to the monitor control subsystem. The monitor control subsystem receives these messages and implements the corresponding display and alarm, ensuring that the baby is safe and monitored at all times. With the Bluetooth module in place, the monitor subsystem can be updated in real-time, giving parents peace of mind that their child is being carefully watched and protected.

For our purpose, we have four ultrasonic sensors, which occupy eight digital pins. We also have a pressure sensor matrix, which requires five analog pins. Lastly, we have a Bluetooth module and a sound detector, which require two digital pins and one analog pin separately. However, this pin assignment is still tolerable under the choice of ATmega328p.
Other than the pins from sensors and communication, I also implemented a few designs on the MCU programming. I added a USBASP port such that the microcontroller is programmable and a 16MHz crystal oscillator to serve as the MCU clock generation.

Investigating the Microprocessor
We need to choose the appropriate MCU for our control subsystem. Since we plan to prototype everything on the breadboard with the Arduino Uno development board, the microprocessor ATmega328p is a decent choice. Therefore, I did some research about this MCU to see if it can tolerate those pin assignments.

The ATmega328P microcontroller has a total of 28 pins, each with a specific function that can be configured by the user. These pins are arranged in two rows, with 14 pins in each row. The pin assignments for the ATmega328P microcontroller are as follows[2]:
- Pins 1 and 2: These are the crystal oscillator pins, used to connect an external oscillator for clock generation.
- Pins 3 and 4: These are the reset pins, used to reset the microcontroller.
- Pins 5 to 12: These are the digital input/output pins, numbered 0 to 7 respectively.
- Pin 13: This is a special digital output pin that is connected to an LED on many development boards.
- Pins 14 to 19: These are analog input pins, also used for digital input/output functions.
- Pins 20 and 22: These are the ground pins.
- Pins 21 and 27: These are the voltage supply pins. Pin 21 is connected to VCC, which is typically 5V, while pin 27 is connected to AVCC, which is the supply voltage for the analog-to-digital converter (ADC).
- Pins 23 to 26: These are the digital input/output pins, numbered 8 to 11 respectively.
- Pin 28: This is the analog comparator output pin.
By configuring these pins, we can control various functions of the microcontroller, such as reading sensor inputs, controlling motors, and communicating with other devices.


Figure 1. Crib Control Subsystem without Bluetooth Module Schematic

Researching Bluetooth Module
Since our project will include pairing two Bluetooth modules, it requires a Bluetooth module that can be set to the master mode. In this case, the HC-05 Bluetooth module is chosen.
There are two operating modes for the HC-05 Bluetooth module.
1. Data mode: In this mode, HC-05 sends and receives data based on Bluetooth protocols through the ports defined as Serial pins.
2. ATCommand mode: HC-05 stops transmitting data and is ready for configuration from ATCommands.
The following figure shows the interfacing of the HC-05 Bluetooth module. As the figure depicts, I only need four of these pins:
1. Vcc pin(connect to 5 V)
2. GND pin(connect to 0 V)
3. RX(connect to Arduino UNO TX pin)
4. TX(connect to Arduino UNO RX pin)

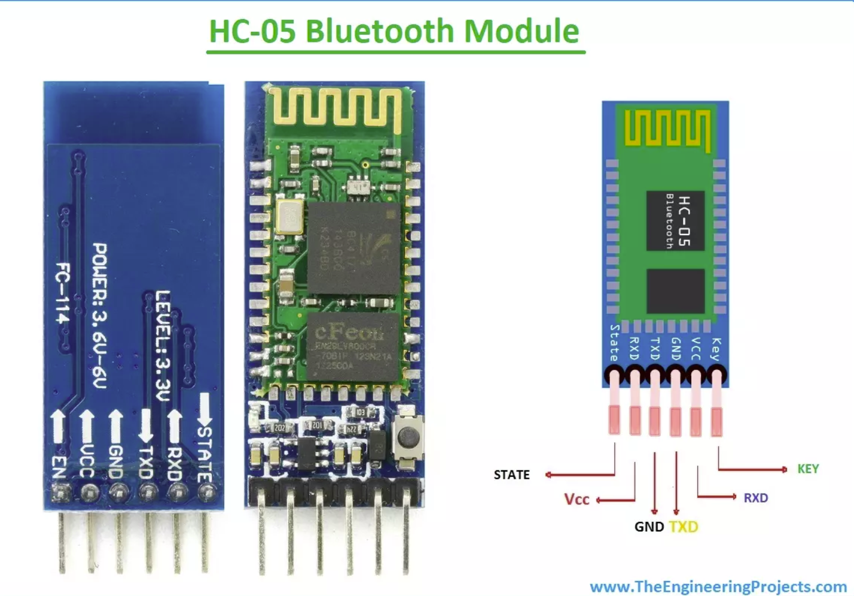
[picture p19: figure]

Figure 2. HC-05 Bluetooth Module Pin Assignments

It is also important to note that the RX pin of the HC-05 requires a maximum 3.3 V voltage instead of 5 V. To achieve this, I applied a voltage divider such that the voltage swing at the RX port is between 0 to 3.3 V.


Figure 3. Crib Control Subsystem Bluetooth Module Schematic

To physically pair two HC-05 Bluetooth modules, we need to set both devices into the ATCommand mode. What I did is first power off the HC-05, press and hold the button on the module, and re-connect the power. The device then enters the ATCommand mode and is ready for configuration. Then I set up the following commands on the slave and master devices, separately [3]:
Slave Device
1. “AT+ROLE=0” sets the device itself to become slave mode.
2. “AT+ADDR?” gets the address of the slave Bluetooth module. Master Device
3. “AT+ROLE=1” sets the device itself to become master mode.
4. “AT+CMODE = 1” sets the address of the slave Bluetooth module.
5. “AT+BIND = Address of the slave Bluetooth module”.

After these procedures, I re-connected these modules to power. The LEDs on the Bluetooth modules shine around once per two seconds, indicating that they have successfully paired.

Regarding the verification, I have already configured our Bluetooth modules through Arduino. Using the Arduino Uno development boards, we can successfully transmit and receive the data. But the data must be sent out in the format of an ASCII value, and the receiver end decodes that ASCII value and can print out its corresponding character.

Power Subsystem
The subsystem is responsible for supplying electricity to the crib PCB board. The board includes a battery source that produces 9 volts and has a capacity of 1300 milliampere-hour, along with a linear voltage regulator. The regulator is used to convert the 9 volts into 5 volts, which is achieved by following a specific formula as stated in reference [4].

V

OUT = 1. 25 V × (1 +

R
2
R
1

)
To ensure that the sensors and MCU receive a 5 V power supply, we select values for R2 and R1 in a way that maintains a proportion of three, resulting in a 5 V output voltage. These components make up the majority of the power requirements for the system. A switch is inserted between the voltage regulator input and the battery such that it can be electronically turned on and off.


Figure 4. Crib Power Subsystem Circuit Schematic

We’ve brought the components to the ECEB 2070 to test the voltage regulator. It turns out that if we keep the R1 and R2 at the same ratio as 3, the output voltage supply will be 4.9V, which is approximately near the 5 V supply voltage.

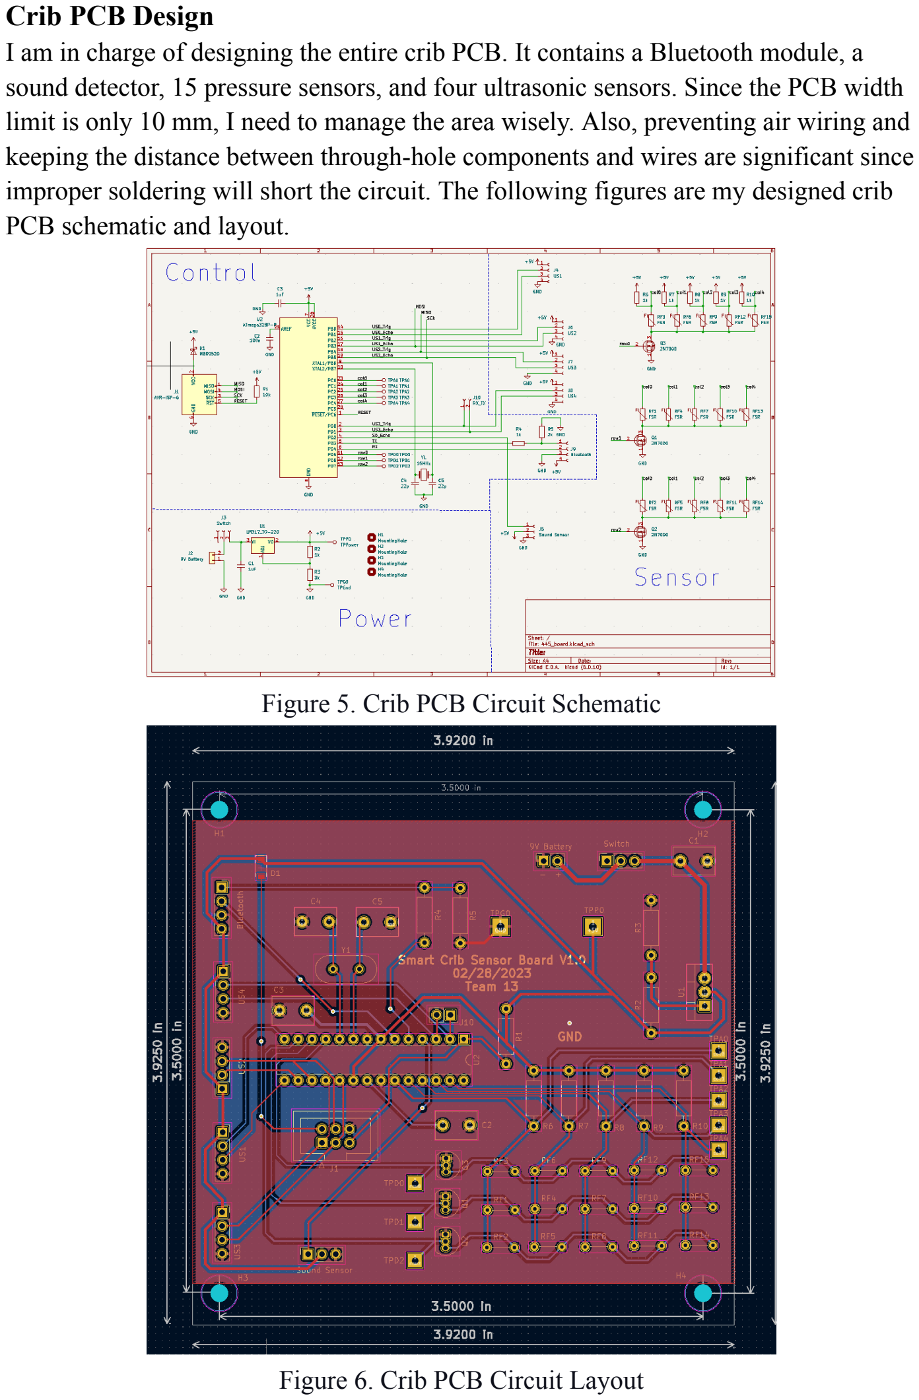
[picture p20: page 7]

Crib PCB Design
I am in charge of designing the entire crib PCB. It contains a Bluetooth module, a sound detector, 15 pressure sensors, and four ultrasonic sensors. Since the PCB width limit is only 10 mm, I need to manage the area wisely. Also, preventing air wiring and keeping the distance between through-hole components and wires are significant since improper soldering will short the circuit. The following figures are my designed crib PCB schematic and layout.

Figure 5. Crib PCB Circuit Schematic

Figure 6. Crib PCB Circuit Layout

### Conclusion

Regarding future planning, I will still be in charge of fixing bugs in my designed PCBs if issues are encountered and re-submit them for fabrication if necessary. Since our team will integrate everything, I will also solder the parts I’ve designed. The following form is the timeline for completing my responsibilities and our project.
3/26-4/1 | Fix bugs and reorder the PCB if necessary and solder crib control and power subsystems on my designed PCB.
4/2-4/8 | Verify the entire hardware in the designed PCB.
4/9-4/15 | Continuing verifying the hardware if necessary. Integrate all the subsystems together, and prepare for the mock demo
4/16-4/22 | Revise the project in detail if necessary and work on preparing the final demo
4/23-4/29 | Work on the final report
Table 1. Timeline for Project Completion As an ethical reminder, I am consistently and will continue to help other team members on their responsibilities if issues arise and they cannot figure them out themselves.

### Reference

[1]“ATMEGA328P - Microchip Technology.” [Online]. Available: https://www.microchip.com/en-us/product/ATMEGA328P. [Accessed: 28-Mar-2023].

[2]-Website Author Syed Zain Nasir syedzainnasir I am Syed Zain Nasir, shayantikadhar Says: and kodjo Says: “HC-05 Bluetooth module pinout, Datasheet, features & applications,” The Engineering Projects, 22-Jun-2021. [Online]. Available: https://www.theengineeringprojects.com/2019/10/hc-05-bluetooth-module-pinout-data sheet-features-applications.html. [Accessed: 28-Mar-2023].

[3]-Website Author Syed Zain Nasir syedzainnasir I am Syed Zain Nasir, shayantikadhar Says: and kodjo Says: “HC-05 Bluetooth module pinout, Datasheet, features & applications,” The Engineering Projects, 22-Jun-2021. [Online]. Available: https://www.theengineeringprojects.com/2019/10/hc-05-bluetooth-module-pinout-data sheet-features-applications.html. [Accessed: 28-Mar-2023].

[4] "LM317 3-Terminal Adjustable Regulator," [Online]. Available: https://www.ti.com/lit/ds/symlink/lm317.pdf?ts=1666119013015&ref_url=https%253 A%252F%252Fwww. google.com%252F

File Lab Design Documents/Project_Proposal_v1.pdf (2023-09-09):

UNIVERSITY OF ILLINOIS AT

URBANA-CHAMPAIGN

## ECE 445: Project Proposal

### Safe Crib with Auto-hazard Detection

SPRING 2023

Xinlong Dai
Yuhao Yuan
Feng Zhao

January 29, 2023

## DESCRIPTION

### 1. Introduction

### 1.1 Problem

Parents with babies at home are most worried about the safety of their babies. Even at home, they always worry that when dealing with things in another room, the baby will not accidentally climb out of the crib or bump into the head of the bed, which might fall off the bed and therefore induce serious injuries [1]. Besides, when babies cry, they usually demand feeding or diaper change. Neglecting the former leads to malnutrition, and the latter causes parents to spend extra time cleaning the bed sheets. Other than that, crying refers to many different signals to parents, such as sickness and burping, indicating the significance of crying for parents to take care of their babies [2]. Based on these considerations, our team aims to design a device to remind parents to take care of their babies.

### 1.2 Solution

Our team proposed a safe crib with hazard detection to solve this problem. The crib can utilize several types of sensors to detect the state of the baby and alarm parents to take care of the baby if necessary.
1. The crib contains ultrasonic sensors on the top of the guardrail, detecting if the baby is trying to climb the guardrail, which might induce falling off the crib.
2. Several pressure sensors are placed beneath the mattress of the bed, forming a matrix to detect the rough position of the baby and if they are crawling.
3. A sound sensor is positioned on the guardrail. If the baby is crying, indicating the need for food or a restroom, the sound sensor will detect that voice.
4. A transmitter analyzes the above situations and sends activation signals to a remote device to display the message.
5. A remote device is necessary to receive the activation signal from the crib. A screen on this device would display the message indicating the following states of the baby, which are:
a. Climbing (background will turn yellow)
b. Crying (background will turn red)
c. Crawling (background will turn red)
The buzzer would sound once the abnormal situations b and c happen. The screen will show the default display if the baby is asleep and not in the above states.

1

### 1.3 Visual Aid

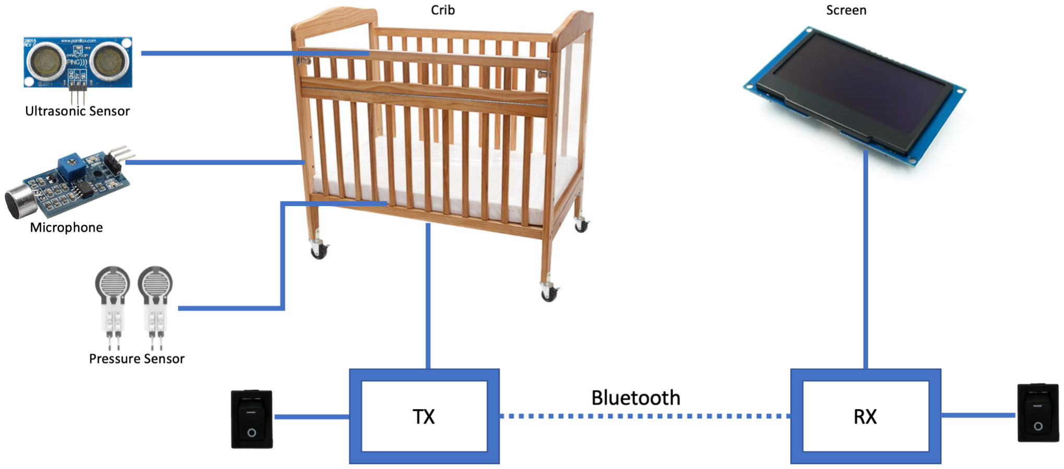
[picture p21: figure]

Figure 1.1 Visual Aid of Smart Crib

### 1.4 High-level requirements list

1. The crib must be capable of alarming parents once their children perform abnormal or hazardous actions, such as crying or trying to climb the guardrails when parents are within 10 m of the crib.
2. The crib must continuously send a “safe” signal when there is no anomaly or send the quiet “baby is crawling” signal.
3. After the crib system processes data from sensors and sends a signal to the receiver, the receiver at the parents’ side must obtain all the information and sound the alarm within 0.5 s;
4. The sound sensor must be able to detect a baby’s crying by sending information to parents once the amplitude exceeds 110 dB.

2

### 2. Design

### 2.1 Block Diagram

Figure 2.1 depicts the entire high-level design of the crib. All of the components are tolerant with an input voltage of 5 V. ATMega328 is considered to be the MCU, which has 14 digital I/O pins and six analog-read pins [3]. Since no more than five ultrasonic sensors and six pressure sensors would be used in this project (each ultrasonic sensor will occupy two digital I/O pins; the sound sensor will occupy one digital I/O pin; the transmission module will occupy two digital I/O pins), the pin assignment is sufficient. Besides, the ease of hand-soldering and basic TTL standard input-voltage tolerance make this chip suitable for our project.

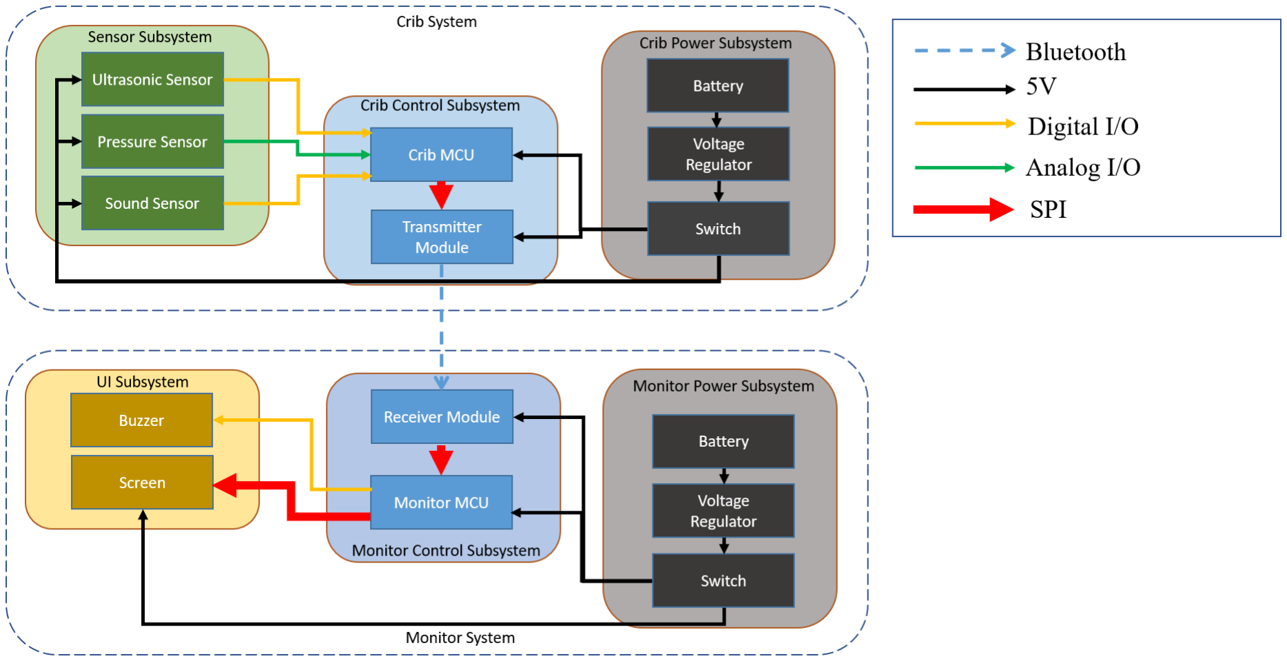
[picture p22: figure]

Figure 2.1 Block Diagram of Smart Crib

### 2.2 Subsystem Overview

### 2.2.1 Crib and Monitor Power Subsystems

The power subsystem offers the power supply to all other components. The 5 V power supply provides power for the transmitting and receiving PCB. The transmitting PCB will use this voltage to power the crib and monitor subsystem, sensor subsystem, and user interface subsystem. And the receiving end will use 5 V to power the monitor and buzzer. The power subsystem also has one switch on each PCB board/Raspberry Pi device to turn on/off the entire crib and monitor control subsystem and all other subsystems connected.

3

### 2.2.2 Sensor Subsystem

The system will use HC-SR04 (Ultrasonic Sensor) to detect the baby's current height and distance to the bed edge through several ultrasonic sensors installed at the top of the guardrail on one side of the bed. Because when lying down or climbing, their height generally does not exceed the height of the guardrail. The system can consider the baby at a potentially dangerous height if the ultrasound is blocked. The system also uses multiple pressure sensors placed between the sheet and the mattress to detect the pressure of the baby on the bed and sends data from each pressure sensor to the crib control subsystem for subsequent processing. The sound sensor is also one subsystem component that detects whether the crying sound is higher than a certain threshold. It then sends an activation signal to the MCU of the crib control subsystem.

### 2.2.3 Crib and Monitor Control Subsystems

MCU is the hardware core of the whole project. It receives the electrical pulse signal from the ultrasonic sensor subsystem and the voltage signal from the pressure sensor subsystem. Then it calculates the distance and pressure change measured by the ultrasonic wave through the code burned on the PCB to determine whether the baby is performing dangerous actions or is carrying out activities while awake. In addition, the corresponding activation signal converts the analog signal into a digital signal through Bluetooth/Wi-Fi module, transmits, and propagates through the antenna. The digital signal is converted back to an analog signal and read by the receiving end of another MCU.

### 2.2.4 User Interface Subsystem

The UI Subsystem was responsible for bringing text prompts to the screen and playing a beep through the buzzer. The system receives control signals from the MCU at the receiving end, extracts text data from the MCU memory, and feeds it into a screen. A buzzer will sound a warning (beeping), respectively.

### 2.3 Subsystem Requirements

### 2.3.1 Crib and Monitor Power Subsystems

The power subsystem offers the power supply to all other components. The 5 V power supply provides power for the transmitting and receiving PCB. Before the current enters the PCB, it passes through a voltage regulator to control the voltage at 5 V ± 0.1 V. Since all the other subsystems use 5V inputs, there is no need for any transformer after passing through the PCB board.
1. The voltage supplied to the crib subsystem needs to be at 5 V ± 0.1 V.
2. The voltage supplied to the monitor subsystem needs to be at 5 V ± 0.1 V.

### 2.3.2 Sensor Subsystem

The system contains three types of sensors: pressure, ultrasound, and sound pressure level. The pressure sensors are placed under the sheet on top of the mattress in our design. The pressure

4

sensors are almost thin cuboids. When pressure is applied to the sensor, its upper and lower layer will connect through a pressure-sensitive layer and reduce the internal resistance. A voltage with its magnitude linearly proportional to that resistance will consequently flow into the MCU, which then detects the corresponding pressure change above the sensor based on reading the voltage difference. According to the value detected by each sensor, the baby’s position and corresponding posture on the bed can be estimated. For example, when the value of only one or two sensors is large, while the value of other sensors is almost zero, the baby should be standing. When four or five sensors detect a certain pressure, the baby is considered kneeling or climbing. The baby is lying flat when nearly 70% or more of the sensors detect a certain pressure. The amount of pressure should decrease in sequence.
1. The analog output from the pressure sensor is between 1 V ± 0.1 V and 5 V ± 0.1 V according to the force exerted on it.
2. The pressure sensor needs to be able to tell 5 N differences of changes in force.

Then there is the sound sensor, which can be set to a threshold; in our design, it is 110 dB. When the sensor detects a baby crying louder than that volume, the sound sensor sends a pulse to the MCU, determining that the baby is awake.
1. The voltage supplied to the sound sensor needs to be at 5 V ± 0.1 V.
2. The output coming from the sound sensor needs to be in the range of 3.3 V to 5 V ± 0.1V when the ambient noise goes above the threshold.
3. The sound sensor needs to send a TTL signal to the MCU when it detects a sound of 110 dB.

Finally, it is the ultrasonic sensor. Several ultrasonic sensors will be arranged at the top of the guardrail on one side of the bed. Due to the directivity of the ultrasonic waves emitted by the ultrasonic sensors and the radiation angle of 14, the ultrasonic waves will not interfere too much with each other. Typically, the ultrasound is not blocked or absorbed, so it takes longer to return or fails to reflect. When the baby is standing, it blocks the ultrasound from the sensor in its position, which means it takes less time to complete a round trip. When the MCU subsystem sends a signal to the ultrasonic sensor to measure the distance, it sends a digital signal. When the ultrasonic sensor receives that signal, it starts sending ultrasonic waves. When the ultrasonic waves are blocked by the baby’s body and reflected, the receiver attached to the sensor will receive the ultrasonic feedback and generate an electrical pulse in the induction circuit inside the sensor to transmit to the MCU. The MCU will calculate the time between sending the test signal and receiving the electrical pulse from the ultrasonic sensor subsystem and then multiply the speed of the sound wave to calculate the distance.
1. The voltage supplied to the ultrasonic sensor needs to be at 5 V ± 0.1 V.
2. The input to the ultrasonic sensor needs to be at 5 V ± 0.1 V when an ultrasound beam needs to be emitted.
3. The output from the ultrasonic sensor needs to be at 5 V ± 0.1 V when the emitted ultrasound beam is reflected and collected.
5

4. The ultrasonic sensor needs to be able to detect a change in distance within 2 m.

### 2.3.3 Crib and Monitor Control Subsystems

These subsystems are for the judgment of situations and data transmission. When the MCU communicates with the sensor subsystem, it will send an electrical signal to notify the sensor to start working and read from the sensors. For example, the pressure sensor will report analog voltages; the ultrasonic sensor will receive a TTL pulse when MCU asks it to emit an ultrasound and send one back when the ultrasound is received; the sound sensor will send a TTL signal when the detected sound exceeds the threshold.

The MCU analyzes and processes this information and performs the following filters. Under usual conditions, the sound sensor does not alarm, while the pressure sensor constantly reports the pressure distribution on the bed. Based on this data, the MCU will determine if the baby crawls on the bed and transmit the corresponding encrypted signal (“crawling”) via Bluetooth or Wi-Fi to the receiving Bluetooth/Wi-Fi module. When the baby cries, the “crying” signal will be sent, and the alarm will sound. Whenever the ultrasonic sensor detects the baby crossing a safe altitude, the MCU determines that the baby is performing a dangerous action and immediately sends a corresponding encrypted signal (“the baby has exceeded the safe altitude”) to the receiver. In these three cases, the MCU of the receiving end will decode the encrypted signal, extract the text information stored in memory according to the decoded content and show it on the screen. At the same time, it will activate the buzzer installed on the PCB of the receiving end for the sound alarm.
1. The voltage supplied to the MCU needs to be at 5 V ± 0.1 V.
2. The MCU working in the crib system needs to work at a clock frequency of at least 10 kHz.

### 2.3.4 User Interface Subsystem

The UI subsystem consists of the screen and the buzzer. When the system receives the text information and activation signal from the PCB at the receiving end, the screen will display the text image by arranging pixels on the pixel screen. At the same time, the buzzer will buzz.
1. The voltage supplied to the screen needs to be at 5 V ± 0.1 V.
2. The screen requires a data transfer rate of 1.2 Mbit/s.
3. The buzzer needs to maintain each alarm at 10 s ± 0.1 s.

### 2.4 Tolerance Analysis

The most likely error in this project is the measurement accuracy and error of the pressure sensor. Tolerance analysis is therefore required to analyze the extent to which potential measurement errors affect the operation of pressure sensors. We can take the lightest of the target population, a seven-month-old baby whose average weight is 8.4 kg (18.5 lbs). According to the formula G = mg with g = 9.8 m/s, the pressure exerted by the baby on the bed surface is 8.4 × 9.8 = 82.32 N. Due to the baby’s small size, when the infant is in a standing position, the projected area on the ground will

6

only occupy the detection range of one sensor so that the sensor will measure the pressure of 82.32
N. When the infant crawls on all fours in a kneeling position, the contact area between the infant’s body and the ground will occupy the range of about four sensors. Because the contact area has been expanded four times, ideally, the pressure measured by each sensor should be one-quarter of the original, that is, 82.32 N / 4 = 20.58 N. Similarly, when the baby is lying, we can think of it as occupying six pressure sensors, and each sensor should measure some value close to 82.32 N / 6 = 13.72 N. We can see that the values detected by each sensor differ greatly in the infant’s standing and lying posture, and the difference between kneeling and lying posture is close to 7 N directly, while the error of the general pressure sensor is between 1 N and 2 N. Therefore, the difference between these three postures is very large, and it is not easy to misjudge. There is little difference between the pressure measured when the baby’s body occupies a range of six sensors for the lying position. Therefore, to avoid wrong judgment, we should define the tolerance as 7 N.

7

### 3. Ethics and Safety

We will thoroughly discuss any ethical issues related to this project in this section. The IEEE Policies [4] has recognized the possible impact of new technologies on the world and emphasized the standard that IEEE members should hold in professional activities. Those more relevant to our project include putting public safety, health, and welfare in the first place, maintaining sustainability, and disclosing possible harms during the use of our product.

We will discuss possible ethical issues related to the product and its development process and will first go through those about the product. When a user considers our product, a primary concern is its safety. Due to the lack of studies on the influence of ultrasound on post-natal infants, we can learn some insights from how ultrasound affects humans in general. We will use sensors that emit ultrasounds with a frequency of around 40 kHz. According to [5], there has been no demonstration showing that ultrasound with 40 kHz and below 120 dB sound pressure level can affect human hearing. Ultrasound with the same scale will also not affect cognitive functions [6]. The working power of our ultrasonic sensor is 75 mW. Assuming all the power is converted to sound, the sound pressure level is 108 dB, which is less than 120 dB. In terms of the influence on biological tissues, ultrasonic devices used at the diagnostic level will not damage human tissue because the produced heat is negligible compared to physiological thermal temperature [7]. Since our product controls the angle and pattern of ultrasound emissions, the baby will not be directly radiated by the ultrasound unless they go beyond the guardrail of the crib, at which time the guardian alarm will sound. The ultrasound radiation time will be less than five minutes per day, assuming the product is turned on for 24 hours per day. In order to prevent fire caused by a short circuit in the pressure sensor lining, we will use special fireproof, waterproof, and insulating materials to package the circuit. When the user wants to wash the lining, they should only wash the waterproof layer after separating it from the lining. When the crib system is not in use, the guardian should unplug the system and put the power cable away so that the baby does not get tripped or entangled by the cable or injured by electricity.

There are fewer concerns in terms of ethical issues in the product development process. The ultrasonic transducer will not cause damage to the developers, as indicated by [5-7]. The ultrasonic sensor will not directly radiate the developers 99% of the time. The developers will need to ensure safe operation and insulation measures when using 5 V power. We will ensure that the development process reflects sustainable development. We will plan ahead all the materials needed and avoid as much waste as possible.

8

There is no safety and regulatory standard on the limit of the frequency and acoustic intensity of ultrasound for non-clinical and consumer products. If we compare our product against the limit specified in part 2 of IEC 60601 for clinical-use products [8], our estimated ultrasound intensity – which is 0.0133 W/cm – is much less than the 3 W/ limit, and the frequency is much higher ² cm

2
than human audible range while in the low-frequency ultrasound range which is safe for human.

9

10

Reference

[1] C. Whitten, "What to Do When Your Baby Falls," WebMD, [Online]. Available: https://www.webmd.com/parenting/baby/what-to-do-when-baby-falls.
[2] "Decoding your baby's cry," baby gooroo, [Online]. Available: https://babygooroo.com/articles/decoding-your-babys-cry.
[3] "Atmega328 Pinout," Learning about Electronics, [Online]. Available: http://www.learningaboutelectronics.com/Articles/Atmega328-pinout.php.
[4] "IEEE POLICIES," 2023. [Online]. Available: https://www.ieee.org/content/dam/ieee-org/ieee/web/org/about/corporate/ieee-policies.pdf.
[5] A. D. Battista, "The effect of 40 kHz ultrasonic noise exposure on human hearing," in Proceedings of the 23rd International Congress on Acoustics, Aachen, 2019.
[6] A. D. Battista, A. Price, R. Malkin, B. W. Drinkwater, P. Kuberka and C. Jarrold, "The effects of high-intensity 40 kHz ultrasound on cognitive function," Applied Acoustics, vol. 200, Nov 2022.
[7] D. B. Moyano, D. A. Paraiso and R. A. González-Lezcano, "Possible Effects on Health of Ultrasound Exposure, Risk Factors in the Work Environment and Occupational Safety Review," Healthcare, Feb 2022.
[8] F. A. Duck, "Medical and non-medical protection standards for ultrasound and infrasound," Progress in Biophysics and Molecular Biology, vol. 93, no. 1-3, pp. 176-191, 2007.

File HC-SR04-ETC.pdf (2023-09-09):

## HC-SR04 Ultrasonic Sensor

### Elijah J. Morgan Nov. 16 2014

The purpose of this file is to explain how the HC-SR04 works. It will give a brief explanation of how ultrasonic sensors work in general. It will also explain how to wire the sensor up to a microcontroller and how to take/interpret readings. It will also discuss some sources of errors and bad readings.

### 1. How Ultrasonic Sensors Work 2. HC-SR04 Specifications 3. Timing chart, Pin explanations and Taking

Distance Measurements

### 4. Wiring HC-SR04 with a microcontroller 5. Errors and Bad Readings

### 1. How Ultrasonic Sensors Work

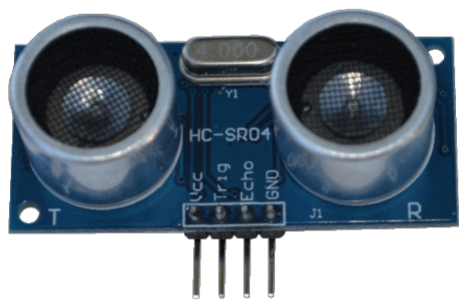
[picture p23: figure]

Ultrasonic sensors use sound to determine the distance between the sensor and the closest object in its path. How do ultrasonic sensors do this? Ultrasonic sensors are essentially sound sensors, but they operate at a frequency above human hearing.

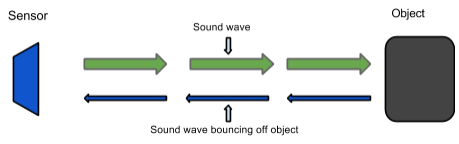
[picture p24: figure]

The sensor sends out a sound wave at a specific frequency. It then listens for that specific sound wave to bounce off of an object and come back (Figure 1). The sensor keeps track of the time between sending the sound wave and the sound wave returning. If you know how fast something is going and how long it is traveling you can find the distance traveled with equation 1.

Equation 1. d = v × t

The speed of sound can be calculated based on the a variety of atmospheric conditions, including temperature, humidity and pressure. Actually calculating the distance will be shown later on in this document.
It should be noted that ultrasonic sensors have a cone of detection, the angle of this cone varies with distance, Figure 2 show this relation. The ability of a sensor to detect an object also depends on the objects orientation to the sensor. If an object doesn’t present a flat surface to the sensor then it is possible the sound wave will bounce off the object in a way that it does not return to the sensor.


### 2. HC-SR04 Specifications

The sensor chosen for the Firefighting Drone Project was the HC-SR04. This section contains the specifications and why they are important to the sensor module. The sensor modules requirements are as follows.
- Cost
- Weight
- Community of hobbyists and support
- Accuracy of object detection
- Probability of working in a smoky environment
- Ease of use
The HC-SR04 Specifications are listed below. These specifications are from the Cytron Technologies HC-SR04 User’s Manual (source 1).
- Power Supply: +5V DC
- Quiescent Current: <2mA
- Working current: 15mA
- Effectual Angle: <15º
- Ranging Distance: 2-400 cm
- Resolution: 0.3 cm
- Measuring Angle: 30º
- Trigger Input Pulse width: 10uS
- Dimension: 45mm x 20mm x 15mm
- Weight: approx. 10 g

The HC-SR04’s best selling point is its price; it can be purchased at around $2 per unit.

### 3. Timing Chart and Pin Explanations

The HC-SR04 has four pins, VCC, GND, TRIG and ECHO; these pins all have different functions. The VCC and GND pins are the simplest they power the HC-SR04. These pins need to be attached to a +5 volt source and ground respectively. There is a single control pin: the TRIG pin. The TRIG pin is responsible for sending the ultrasonic burst. This pin should be set to HIGH for 10 μs, at which point the HC-SR04 will send out an eight cycle sonic burst at 40 kHZ. After a sonic burst has been sent the ECHO pin will go HIGH. The ECHO pin is the data pin it is used in taking distance measurements. After an ultrasonic burst is sent the pin will go HIGH, it will stay high until an ultrasonic burst is detected back, at which point it will go LOW.
Taking Distance Measurements
The HC-SR04 can be triggered to send out an ultrasonic burst by setting the TRIG pin to HIGH. Once the burst is sent the ECHO pin will automatically go HIGH. This pin will remain HIGH until the the burst hits the sensor again. You can calculate the distance to the object by keeping track of how long the ECHO pin stays HIGH. The time ECHO stays HIGH is the time the burst spent traveling. Using this measurement in equation 1 along with the speed of sound will yield the distance travelled. A summary of this is listed below, along with a visual representation in Figure 2.
1. Set TRIG to HIGH
2. Set a timer when ECHO goes to HIGH
3. Keep the timer running until ECHO goes to LOW
4. Save that time
5. Use equation 1 to determine the distance travelled


Source 2

To interpret the time reading into a distance you need to change equation 1. The clock on the device you are using will probably count in microseconds or smaller. To use equation 1 the speed of sound needs to determined,which is 343 meters per second at standard temperature and pressure. To convert this into more useful form use equation 2 to change from meters per second to microseconds per centimeter. Then equation 3 can be used to easily compute the distance in centimeters.

Equation 2. Distance =

Speed
170.15 m × 100 cm

Meters ×

1e6 μS
170.15 m × cm

58.772 μS

Equation 3. Distance = 58 | m

time =

μs
μs/cm = c

### 4. Wiring the HC-SR04 to a Microcontroller

This section only covers the hardware side. For information on how to integrate the software side, look at one of the links below or look into the specific microcontroller you are using.

The HC-SR04 has 4 pins: VCC, GND, TRIG and ECHO.
1. VCC is a 5v power supply. This should come from the microcontroller
2. GND is a ground pin. Attach to ground on the microcontroller.
3. TRIG should be attached to a GPIO pin that can be set to HIGH
4. ECHO is a little more difficult. The HC-SR04 outputs 5v, which could destroy many microcontroller GPIO pins (the maximum allowed voltage varies). In order to step down the voltage use a single resistor or a voltage divider circuit. Once again this depends on the specific microcontroller you are using, you will need to find out its GPIO maximum voltage and make sure you are below that.


### 5. Errors and Bad Readings

Ultrasonic sensors are great sensors they work well for many applications where other types of sensors fall short. Unfortunately, they do have weaknesses. These weaknesses can be mitigated and worked around, but first they must be understood. The first weakness is that they use sound. There is a limit to how fast ultrasonic sensors can get distance measurements. The longer the distance, the slower they are at reporting the distance. The second weakness comes from the way sound bounces off of objects. In enclosed spaces it is possible, if not probable that there will be unintended echos. The echos can very easily cause false short readings. In Figure 2 a pulse was sent out. It bounced off of object 1 and returned to the sensor. The distance was recorded and then a new pulse was sent. There was another object farther away, so that when the new pulse reaches object 1, the first signal will reach the sensor. This will cause the sensor to think that there is an object closer than is actually true. The old pulse is smaller than the new pulse because it has grown weaker. The longer the pulse exists the weaker it grows until it is negligible. If multiple sensors are being used, the number of echos will increase along with the number of errors. There are two main ways to reduce the number of errors. The first is to provide shielding around the sensor. This prevents echos coming in from angle outside what the sensor should actually pick up. The second is to reduce the frequency at which pulses are sent out. This gives more time for the echos to dissipate.


Works Cited

Source 1.
“HC-SR04 User's_Manual.” docs.google. Cytron Technologies, May 2013 Web. 5 Dec. 2009.
<https://docs.google.com/document/d/1Y-yZnNhMYy7rwhAgyL_pfa39RsB-x2qR4vP8saG73rE/edit>

Source 2.
“Attiny2313 Ultrasonic distance (HR-SR04) example.” CircuitDB. n.a. 7 Sept. 2014 Web. 5 Dec. 2014. <http://www.circuitdb.com/?p=1162>

Links

These are not formatted; you will need to copy and paste them into your web browser.

Want to learn about Ultrasonic Sensors in general? http://www.sensorsmag.com/sensors/acousticultrasound/choosingultrasonicsensorprox imityordistancemeasurement-825

All about the HC-SR04

- http://www.circuitdb.com/?p=1162
- http://www.micropik.com/PDF/HCSR04.pdf
- http://randomnerdtutorials.com/completeguideforultrasonicsensorhcsr04/
- http://www.ezdenki.com/ultrasonic.php
(^fantastic tutorial, explains a lot of stuff)
- http://www.elecrow.com/hcsr04-ultrasonicrangingsensorp-316.html
(^ this one has some cool charts)

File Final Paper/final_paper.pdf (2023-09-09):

# Safe Crib with Auto Hazard-Detection

## ECE 445 Final Report

### Team 13

### Feng Zhao (fengz3)

### Xinlong Dai (xinlong3)

### Yuhao Yuan (yuhaoy3)

### TA: Dushyant Singh Udawat

### Spring 2023

ii

### Abstract

Nowadays, parents find it hard to take care of their baby and ensure their baby’s safety when the baby is in a crib. Our project team created a safe crib solution to help the parents. First, our safe crib can report to the parents about whether the baby is trying to climb out of the crib. Second, the crib can detect the baby’s crying sound and notify the parents, which might indicate that the baby needs care. Third, the crib can notify the parent about whether the baby is moving inside the crib, and the parents can decide whether they need to move their baby out of the crib for activities. Given appropriate packaging, our project has the potential for commercialization.

iii

### Contents

iv

### 1. Introduction

### 1.1 Purpose

Securing an infant's safety within a crib can be challenging, particularly when dealing with active babies. It's known that babies as young as eight months can begin climbing out of their cribs [1]. Continuously monitoring a baby at home is impractical since parents can only sometimes be in the baby's room. Additionally, a baby's cry can signal various needs, such as hunger, a diaper change, illness, or burping. Ignoring these cues can lead to malnutrition, skin irritation, or even bladder infections, highlighting the importance of attending to a crying baby [2].

To resolve this issue, our team proposes an innovative crib equipped with hazard detection. This electronic solution is an innovation to the market as it identifies potential dangers and notifies the parents. The crib employs multiple types of sensors to monitor the baby's state and alerts parents when necessary. Firstly, ultrasonic sensors atop the guardrail detect if the baby is attempting to climb and potentially fall. Secondly, a sound sensor on the guardrail picks up the baby's cry, indicating a need for food or a diaper change. Lastly, pressure sensors arranged in a matrix below the mattress detect the baby's movement within the crib, helping parents decide whether to take care of the baby. The crib system's microcontroller processes the sensor data and communicates any safety concerns to the parents' monitoring system.

### 1.2 Functionality

The project has three high-level functionalities listed below.

1. The safe crib system needs to alert the parents about whether any of the baby’s body parts has reached a height of 20 in from the bottom of the crib. This functionality ensures that parents can be alerted if the baby is trying to climb the guardrail and prevent the baby from falling from the crib and getting hurt.
2. The safe crib system needs to alert the parents about whether the baby’s crying is higher than 86 dB for 2 s when measured at 34 in away. This functionality lets parents be alerted if the baby is crying and come to take care of the baby.
3. When the monitor system is within 10 m of the crib and at most three 11.4 cm or thicker walls from the crib, the crib system needs to be able to send updates to the monitor system at the parent’s side within 3 s of the occurrence of the safety event. This is because the room spacing inside an apartment is 10 m long with walls in between. This functionality notifies parents of the baby’s state and receives alarms on time so that they have enough time to take action to protect the baby.

### 2. Design

### 2.1 Subsystem Overview

As shown in Figure 2.1, the safe crib system consists of six interconnected subsystems. The crib and monitor power subsystems supply a consistent 5 V DC voltage to components within the other subsystems. The sensor subsystem is responsible for gathering data about the baby's current condition and transmitting it to the microcontroller unit (MCU) within the crib control subsystem. The MCU processes this information to determine the baby's status and sends an activation signal to the monitor system via Bluetooth. The monitor control subsystem identifies the baby's current state based on receiving and decoding the activation signal. It directs the user interface (UI) subsystem to display relevant messages about the baby's situation and trigger a buzzer alarm if necessary. Figure 1 and 3 in Appendix A show the schematics for the crib system and the monitor system, and Figure 2 and 4 show their PCB layouts.


Figure 2.1: System Block Diagram

### 2.2 Crib System

### 2.2.1 Crib Sensor Subsystem

The crib sensor subsystem is responsible for collecting the measurements regarding the baby’s current state. Three types of sensors are incorporated inside this subsystem. They are ultrasonic sensors, sound sensors, and pressure sensors.

Four ultrasonic sensors are positioned along one side of the crib edge, forming an ultrasonic sensors array. They connect to the microcontroller via digital I/Os. They constantly measure the distance from one side of the crib to another. When the baby stands up and breaks the measurement, we can tell that the baby has reached the height limit. In principle, the sensor sends an ultrasound, which will soon be echoed back if it hits some objects. The programmable MCU in the control subsystem records the time it takes for the ultrasound to propagate and reflect back to the sensor and calculates the distance based on the recorded time multiplied by the sound speed [3]. The calculation is based on equation (2.1).

distance | = | speed | × | time | =

34 cm
ms
× duration(ms) | (2.1)
One sound sensor is responsible for detecting the surrounding noise intensity and returns a digital “high” voltage, which is considered as an alarm that the baby is crying, to the microcontroller if a sound above our particular interested intensity level threshold is detected, otherwise it returns a digital “low” voltage. Based on our investigation and experiment, we observed that a 100 dB sound [4], the intensity same as the baby’s crying sound, is attenuated to 86 dB near the microphone of the sound sensor. Therefore, we determine the desired threshold to be 86 dB. In the later section, we will verify the sensor can send alarms when the sound intensity level is beyond that threshold.

The pressure sensors are the most sophisticated module to be designed because we encountered a design issue because the microcontroller has its pin shortage since there are five analog pins inside the microcontroller, whereas 15 pressure sensors need for data collection. However, we designed a five-by-three pressure sensor matrix to resolve this issue, as shown in Figure 2.2.


Figure 1.2: Pressure Sensor Matrix Schematic

Since we plan to use 15 pressure sensors, we divide them into three columns such that every five of them forms a pressure sensor row, controlled by an n-channel MOSFET, and its gate is connected to one digital pin of the microcontroller. If the microcontroller sends a 5 V voltage pulse, the MOSFET will generate drain-to-source current and pull its resistance down, thus serving as a switch. We generally use three MOSFETs, each controlling the current flow through a pressure sensor row. Based on this approach, the measurements from all pressure sensors can be recorded without switching to a more advanced microcontroller (ATMega2560, for instance).

### 2.2.2 Crib Control Subsystem

The crib control subsystem is designed to receive and analyze the data from the crib sensor subsystem, generate the corresponding message, and send them to the monitor control subsystem via Bluetooth. Based on this consideration, we connect the Bluetooth module to the microcontroller through the defined serial TX/RX ports and the UART protocol, so it can successfully receive the information from the microcontroller and send them out. In Figure 2.3, the schematic of the crib control visualizes that. Table 2.1 describes our microcontroller pin usage.

Apart from the Bluetooth module, we add an ISP connector to the microcontroller to make it programmable. We also connect an external 16 MHz crystal oscillator with two 22 pF capacitors to the microcontroller to serve as the clock generation [5].

Components | ultrasonic sensors | pressure sensor matrix | sound detector | Bluetooth module
MCU pin type | analog | digital | analog | digital | analog | digital | analog | digital
MCU pin usage | 0 | 8 | 5 | 3 | 1 | 0 | 0 | 2

Table 2.1: MCU pin usage on different types of sensors


Figure 2.3: Crib Control Subsystem Schematic

### 2.2.3 Crib Power Subsystem

The crib power subsystem is responsible for providing the battery to the corresponding subsystems on the crib PCB board. As shown in Figure 2.4, the power source is a 9 V and 1300 mAh rechargeable battery connected to a linear voltage regulator. The regulator converts the input to output voltage based on the equation (2.2) [6]:

VOUT = 1.25 V × (1 +

R2
R1
) | (2.2)

Therefore, to derive a 5 V output, we choose R1 and R2 based on a proportion of 3. For example, choosing R1 and R2 to be 330 Ω and 110 Ω, respectively, allows us to obtain an output voltage of 5 V. Besides, the output current is supposed to be less than 100 mA. Since the power source is 1300 mAh, the power source can maintain operation for more than 10 hours. A switch is placed between the battery and the regulator to control the on/off state of the entire crib system.

Figure 2.4: Crib Power Subsystem Schematic

### 2.3 Monitor System

### 2.3.1 UI Subsystem

The UI subsystem is responsible for notifying parents about the crib's event generation. We used an LCD screen to display a striking visual prompt to parents. Besides, we assigned different background colors and texts when related events happened to differentiate the emergency level. For instance, the screen displays white text with a red background color while the baby is trying to climb over the crib, and the screen displays white text and a green background if the baby is asleep and quiet.

In addition, we placed a buzzer along with the screen for auditory stimuli. We set the buzzer to turn on only if the screen turned red, indicating the highest emergency events, such as climbing over the crib or crying. Table 2.2 describes how the screen and buzzer work under different signals.

Event | Text color | Screen background color | Buzzer State (On/Off)
Climbing over the crib | White | Red | On
Crying | White | Red | On
Crawling | Black | yellow | On once
Staying quiet or asleep | White | Green | Off
Unconnected with crib subsystem | White | Orange | On for every 3 seconds

Table 2.2: Screen and Buzzer Reaction from Different Received Signals

### 2.3.2 Monitor Control Subsystem

The monitor control subsystem is designed for receiving messages from the crib subsystem via Bluetooth and assigning the corresponding instruction to the UI subsystem. The schematic looks similar to the crib control subsystem, as both are composed of a microcontroller, an in-circuit programmer, and a Bluetooth module. Since the more important part is on the software side, we designed a flowchart as in Figure 2.5 to demonstrate the logic of this subsystem.


Figure 2.5 Monitor Control Subsystem Flow Chart

### 2.3.3 Monitor Power Subsystem

We design this subsystem to supply power to the entire monitor system. Like the crib power subsystem, we connect the 9 V battery to the linear voltage regulator with a few resistors and capacitors. Same to the crib power subsystem, the output current needs to be less than 100 mA to ensure the device has enough operation time.

### 3. Cost & Schedule

### 3.1 Cost

### 3.1.1 Labor

We assume the hourly salary is $ 35. And each of us contributes to the project for 12 hours every week. Since there are 15 weeks in a semester, then the labor cost for each member is:

Labor Cost = 35 dollars
ℎour

× 2.5 × 12 ℎours
week

× 15 weeks = $ 15750 (3.1) The total labor cost for a group of three is also calculated:

Total Labor Cost = 3 × $ 15750 = $ 47250 | (3.2)

### 3.1.1 Parts

Table 3.1 shows the information and the cost of each part used in our project.

Description | Manufacturer | Part # | Quantity | Individual Cost ($) | Bulk Cost ($)
Ultrasonic Sensor | EPLZON | HC-SR04 | 4 | $ 2.60 | $ 10.40
Pressure Sensor | DFRobot | SEN0294 | 15 | $ 5.00 | $ 75.00
Sound Sensor | Sparkfun | SEN-14262 | 1 | $ 13.25 | $ 13.25
Microcontroller | Microchip Technology | ATMega328p | 2 | $ 7.70 | $ 15.40
Bluetooth Module | DEVMO | HC-05 | 2 | $ 11.33 | $ 22.66
Buzzer | CUI Devices | CMI-1295IC-0585T | 1 | $ 1.18 | $ 1.18
Screen | Adafruit | ST7789 | 1 | $ 17.50 | $ 17.50
Battery | TQTHL | N/A | 2 | $ 5.22 | $ 10.44
Voltage Regulator | Texas Instruments | LM317KCT | 1 | $ 0.69 | $ 0.69
Switch | Adafruit | 805 | 2 | $ 0.95 | $ 1.90
NMOS Transistor | ONSEMI | 2N7000 | 3 | $ 0.51 | $ 1.53
Total | | | | | $ 169.95

Table 3.1: Parts Cost

### 3.1.3 Sum of Costs

Sum of Costs = $ 47250 + $ 169.95 = $ 47419.95 | (3.3)

### 3.2 Schedule

| Yuhao | Xinlong | Feng
2/5/2022-2/11/2022 | Research part number of the microcontroller & voltage regulator (Including writing the design document) | Research how the screen works. Draw the schematics of the UI system | Prepare all three types of sensors. Research about the testing parameter of the sensor system
2/12/2022-2/18/2022 | Design the Schematics of the Microcontroller & Power Subsystem (Including writing the design document) | Draw the schematics of the UI subsystem & PCB layout. Write design document | Design the connection to the Microcontroller & Power Subsystem and signal processing method
2/19/2022-2/25/2022 | Draw the PCB Layout of the Microcontroller & Power subsystem. Write the design document | Design PCB layout of the UI subsystem. Write the design document | Design a supporting circuit to operate as a central terminal for all pressure sensors. Write the team contract and the design document
2/26/2022-3/4/2023 | Prepare for the design review. Design the prototype of the crib control subsystem | Prepare for the design review. Design the prototype of the monitor control subsystem | Prepare for the design review. Design the prototype of the crib sensor subsystem and adjust sensor parameters.
3/5/2023-3/11/2023 | Adjust the prototype of the crib control and power subsystems | Adjust the prototype of the monitor control and power subsystems | Adjust the prototype of the crib sensor and power subsystems on breadboard
3/12/2023-3/18/2023 | Spring Break | Spring Break | Spring Break
3/19/2023-3/25/2023 | Fix the crib control and power subsystem PCB design if errors are identified in the prototype | Fix the monitor system PCB design if errors are identified in the prototype | Fix the sensor subsystem and PCB design if errors are identified in the prototype

Table 3.2: Team Member Schedule

3/26/2023-4/1/2023 | Order a new PCB in the second round if needed. Write the individual progress report. Integrate parts into the crib system on PCB | Order a new PCB in the second round if needed. Write the individual progress report. Integrate parts into the monitor system on PCB | Order a new PCB in the second round if needed. Write the individual progress report. Integrate parts into the crib system on PCB
4/2/2023-4/8/2023 | Integrate parts into the crib system PCB. Verify the hardware on the same system | Integrate parts into the monitor system PCB. Verify the hardware on the same system | Integrate parts into the crib system PCB. Verify the hardware on the same system
4/9/2023-4/15/2023 | Finish hardware verification. Put subsystems together, and prepare for the mock demo. Build the physical crib model | Finish hardware verification. Put subsystems together, and prepare for the mock demo. Build the physical crib model | Finish hardware verification. Put subsystems together, and prepare for the mock demo. Build the physical crib model
4/16/2023-4/22/2023 | Work on project revision based on the feedback from the mock demo | Work on project revision based on the feedback from the mock demo | Work on project revision based on the feedback from the mock demo
4/23/2023-4/29/2023 | Prepare for the final demo and start the final report | Prepare for the final demo and start the final report | Prepare for the final demo and start the final report
4/30/2023-5/3/2023 | Prepare for the final presentation and finish the final report | Prepare for the final presentation and finish the final report | Prepare for the final presentation and finish the final report

Table 3.2 (continued): Team Member Schedule

### 4. Requirements & Verification

### 4.1 Crib System

### 4.1.1 Crib Sensor Subsystem

To ensure the sensor subsystem functions properly, we need to verify each category of sensors individually. Table 1 in Appendix A introduces some of the requirements we have for these three types of sensors.

The ultrasonic sensor must correctly inform the microcontroller if the baby is climbing, meaning that the baby rises to a height similar to the crib height. To verify this requirement, we mounted the ultrasonic sensors along the top of one side of the crib and uploaded a program to scan the ultrasonic sensor measurements. After turning on the device, we put an obstacle between the sensor and the guardrail. We checked if the horizontal distance between the ultrasonic sensor and the obstacle was smaller than 34 in. In this case, the distance measurements echoed back from the ultrasonic sensors were processed by the crib control subsystem and sent to the monitor, which displayed the information that the baby was climbing out of the crib.

To verify the sound sensor, we placed a speaker and a decibel meter together near the sound sensor. The speaker simulated the baby’s crying, and the meter measured the sound level. We measured the sound level four times and checked the screen display, concluding that the sound sensor performed correctly. Table 4.1 shows some examples of sound levels that are above or below the threshold for the “Crying” alert.

Measured sound level (dB) | Screen display
81.7 | Your baby is safe and quiet :)
84.7 | Your baby is safe and quiet :)
86.1 | Your baby is crying.
87.6 | Your baby is crying.

Table 4.1: Sound Intensity Measurement vs. Screen Display

The pressure sensor matrix is the last section of sensor subsystem components to be verified. We wrote and uploaded a program to scan the measurements from the pressure sensors and put an object of 5 N weight, such as a 500 ml bottle of water, on each pressure sensor. The pressure sensor detected a change in 5 N force since the screen displayed “Baby is moving on the crib,” which indicated that it recognized the change in baby’s position once it felt a 5 N force.

### 4.1.2 Crib Control Subsystem

For the crib control subsystem, we can refer to Table 2 in Appendix A to see more details on the specific requirements of this subsystem.

To test the crib control subsystem, we first verified whether the microcontroller could receive and analyze the sensor data by writing a program to convert sensor measurements into a three-bit bit code as described in Table 4.2, where each of the bits represented one state of the baby.

bit | Sensor | Baby’s state
least significant bit | Ultrasonic Sensor | Is climbing
middle bit | Sound Sensor | Is crying
most significant bit | Pressure Sensor | Is moving

Table 4.2: Bit Assignment of Each Sensor with Baby’s Corresponding State

In this scenario, we uploaded a code into the microcontroller and used serial monitor display to check if the data processing is successful. As Table 4.3 demonstrates, we made each type of sensor respond to a state change of the baby individually and recorded the bit code displayed on the serial monitor.

Sensor | Measurement change | Serial monitor display | Is bit mapping correct
Ultrasonic Sensor | Put obstacle between the sensor and the crib guardrail | 001 | Yes
Sound Sensor | Play a sound with pressure level above 86 dB near the sensor | 010 | Yes
Pressure Sensor | Put a 5 N object on the sensor | 100 | Yes

Table 4.3: Baby’s State Change vs. Bit Code Displayed on the Serial Monitor

Based on the comparisons between the two tables, we concluded that the microcontroller could receive and analyze the data collected from the sensors.

The other requirement is to guarantee successful and fast data transmission from the crib to the monitor with a maximum delay of three seconds. We verified it based on the use of a timer to record the monitor reaction time. Once we changed the sensors' measurement, we started timing until the monitor changed the display from safe to climbing, crying, and moving. We performed 5 trials for each type of sensor and derived the following plot, which is Figure 4.1.


Figure 4.1 Monitor Reaction Time

From the plot, we observed that none of the monitor reaction time measurements exceeded three seconds, indicating the verification was successful.
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

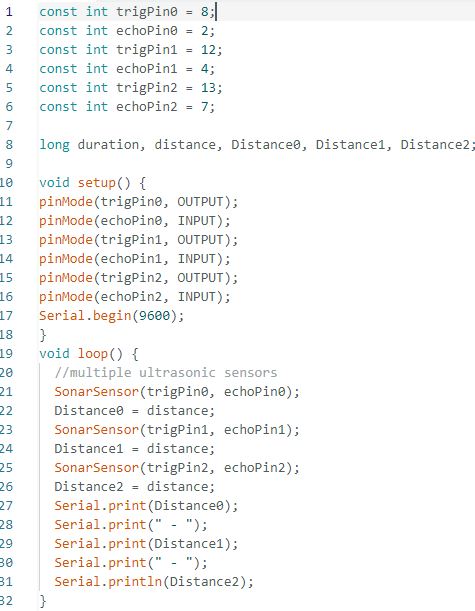
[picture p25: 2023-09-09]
Individual Progress Report/ultrasonic sensor code 1.JPG

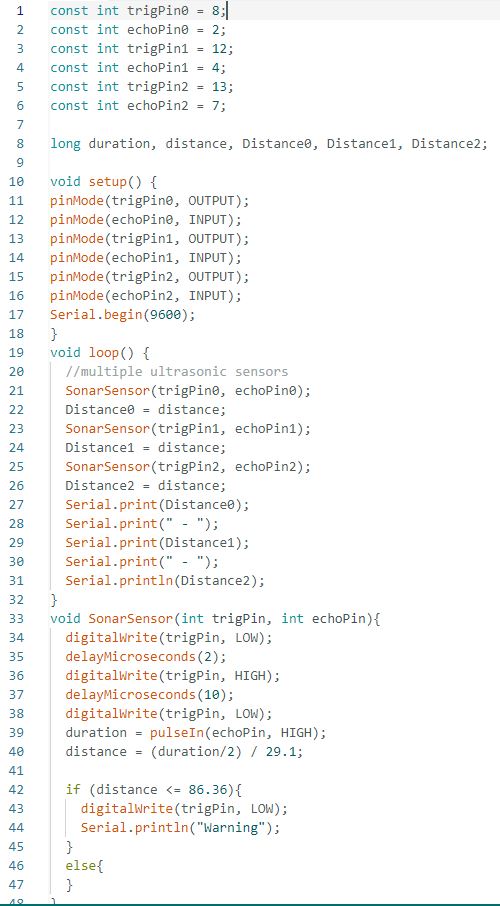
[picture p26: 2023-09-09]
Individual Progress Report/ultrasonic sensor code.JPG

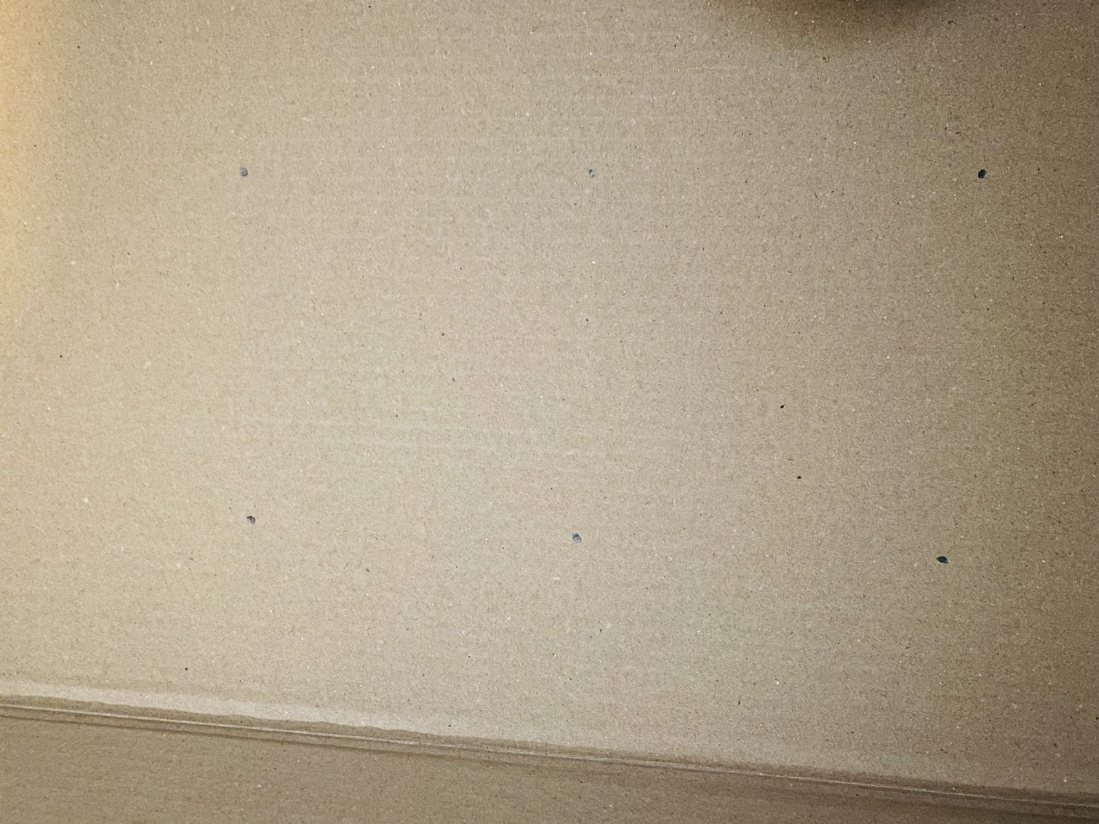
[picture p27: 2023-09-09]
Individual Progress Report/crib model.jpg

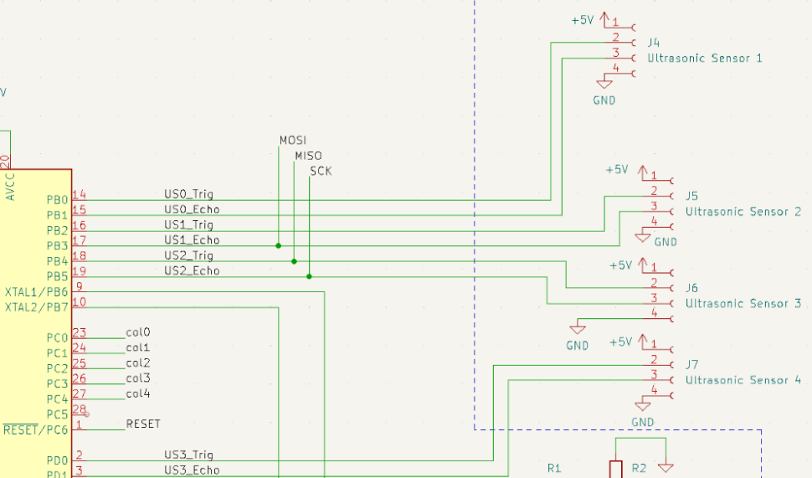
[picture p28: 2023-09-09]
Individual Progress Report/PCB_ultrasonic_sensors.png

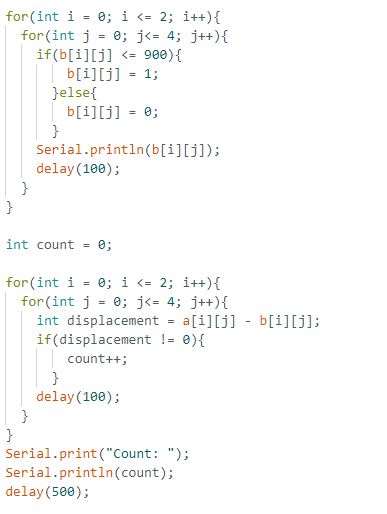
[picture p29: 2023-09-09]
Individual Progress Report/pressure sensor code 2.JPG

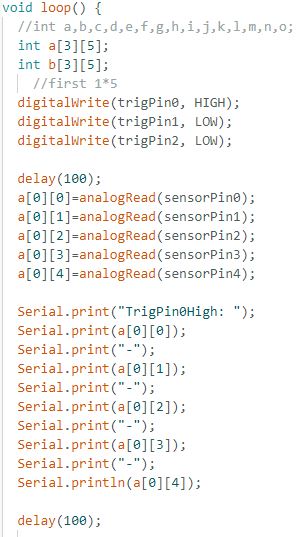
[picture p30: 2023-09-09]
Individual Progress Report/pressure sensor code 1.JPG

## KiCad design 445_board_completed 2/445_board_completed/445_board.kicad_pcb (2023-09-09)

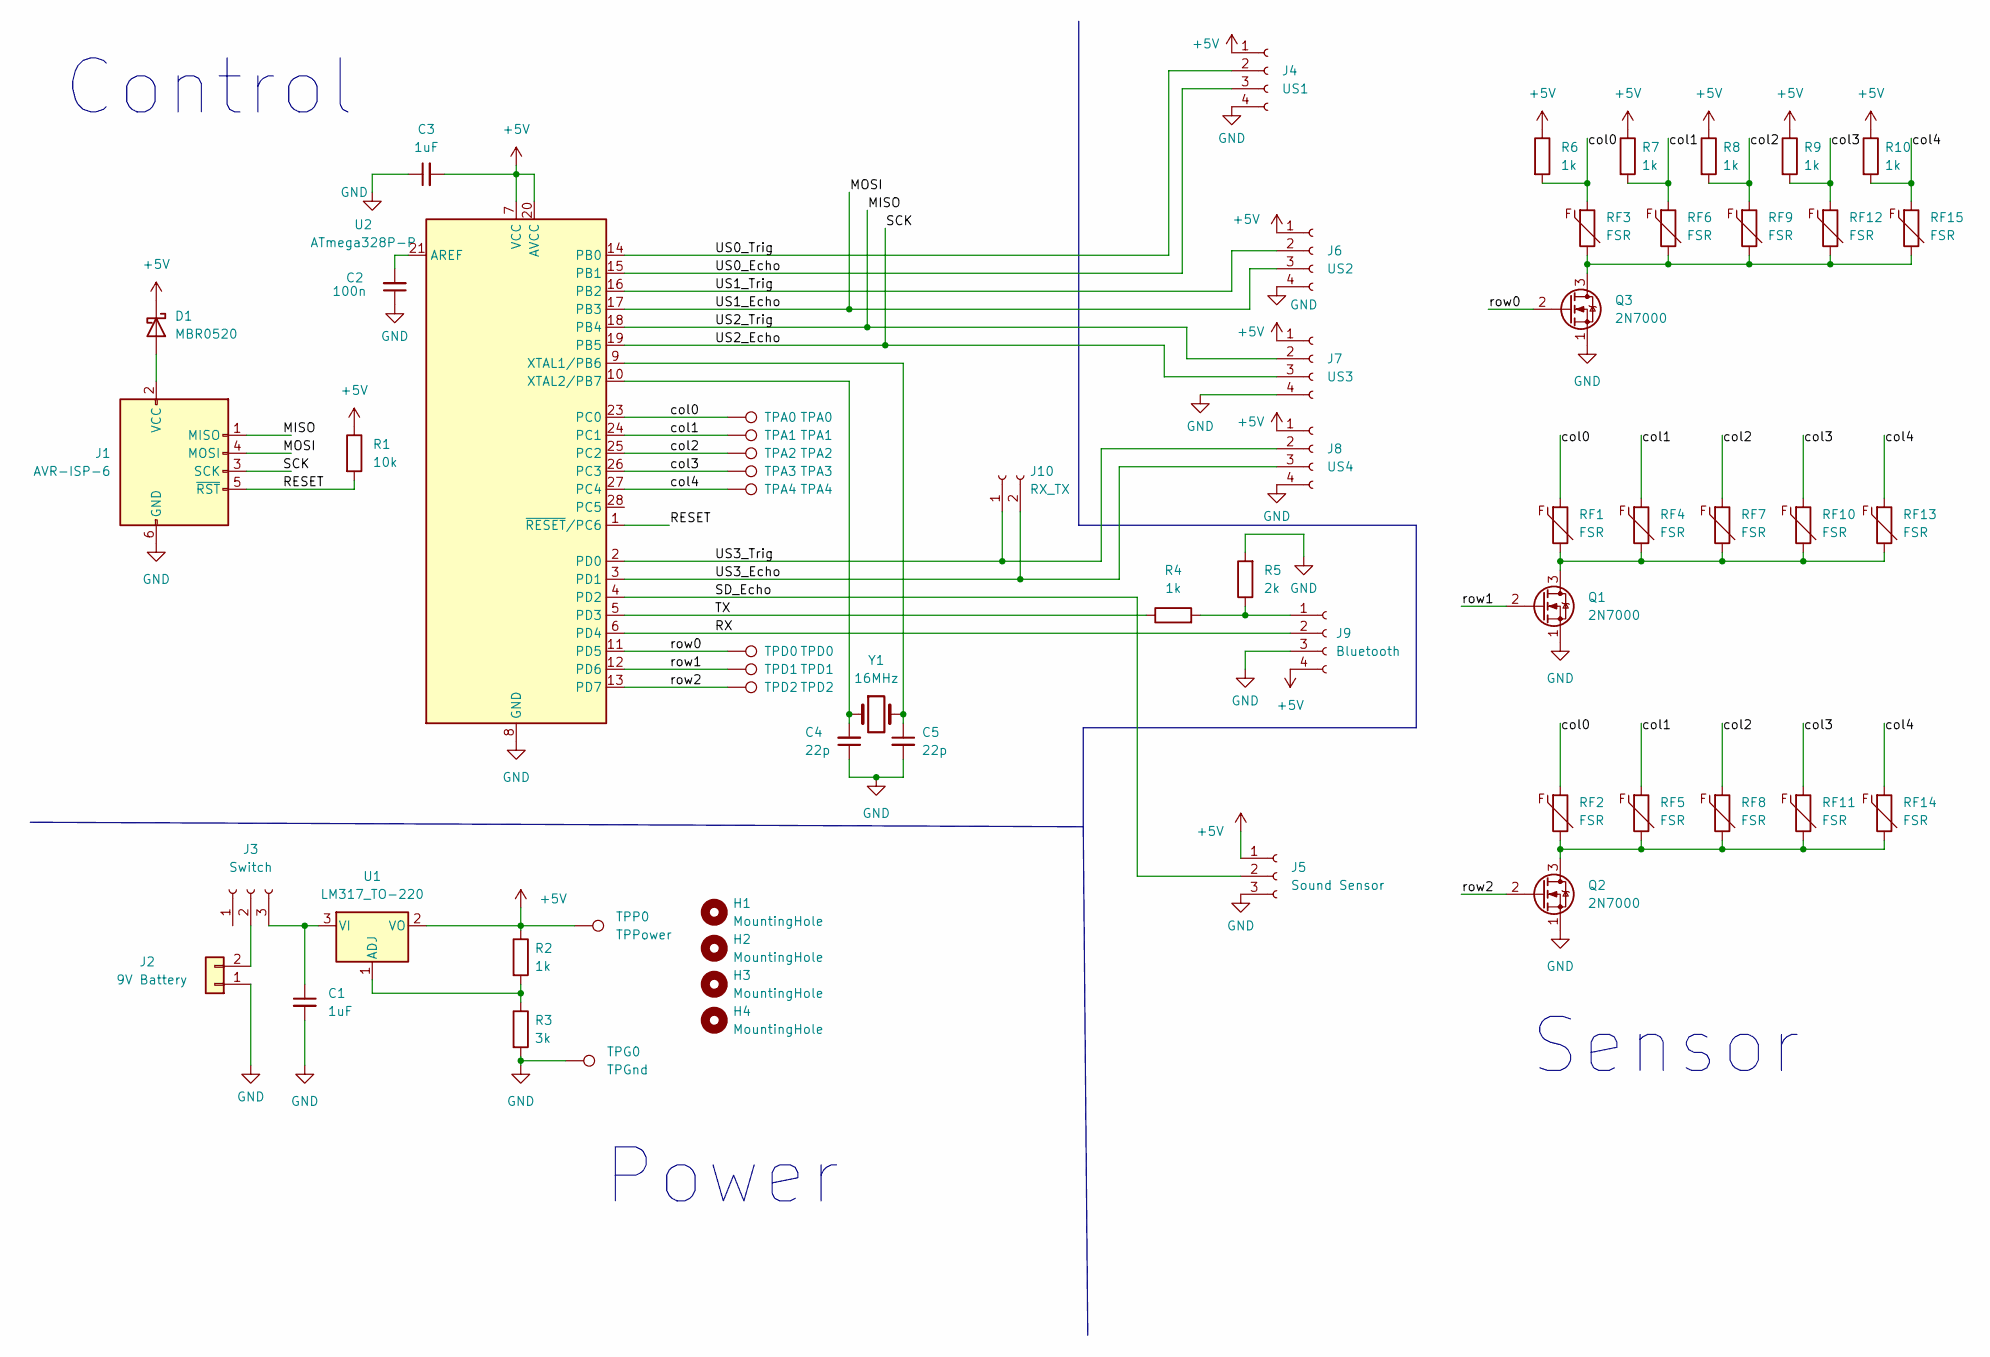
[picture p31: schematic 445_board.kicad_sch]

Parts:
C1, C3: 1uF; C_Disc_D7.5mm_W5.0mm_P5.00mm
C2: 100n; C_Disc_D7.5mm_W5.0mm_P5.00mm
C4, C5: 22p; C_Disc_D7.5mm_W5.0mm_P5.00mm
D1: MBR0520; D_SOD-123
H1, H2, H3, H4: MountingHole; MountingHole_3.2mm_M3
J1: AVR-ISP-6; IDC-Header_2x03_P2.54mm_Vertical
J2: 9V Battery; PinSocket_1x02_P2.54mm_Vertical
J3: Switch; PinSocket_1x03_P2.54mm_Vertical
J4: US1; PinSocket_1x04_P2.54mm_Vertical
J5: Sound Sensor; PinSocket_1x03_P2.54mm_Vertical
J6: US2; PinSocket_1x04_P2.54mm_Vertical
J7: US3; PinSocket_1x04_P2.54mm_Vertical
J8: US4; PinSocket_1x04_P2.54mm_Vertical
J9: Bluetooth; PinSocket_1x04_P2.54mm_Vertical
J10: RX_TX; PinSocket_1x02_P2.54mm_Vertical
Q1, Q2, Q3: 2N7000; TO-92_Inline
R1: 10k; R_Axial_DIN0207_L6.3mm_D2.5mm_P10.16mm_Horizontal
R2, R4, R6, R7, R8, R9, R10: 1k; R_Axial_DIN0207_L6.3mm_D2.5mm_P10.16mm_Horizontal
R3: 3k; R_Axial_DIN0207_L6.3mm_D2.5mm_P10.16mm_Horizontal
R5: 2k; R_Axial_DIN0207_L6.3mm_D2.5mm_P10.16mm_Horizontal
RF1, RF2, RF3, RF4, RF5, RF6, RF7, RF8, RF9, RF10, RF11, RF12, RF13, RF14, RF15: FSR; R_Axial_DIN0204_L3.6mm_D1.6mm_P5.08mm_Vertical
TPA0: TPA0; TestPoint_THTPad_2.5x2.5mm_Drill1.2mm
TPA1: TPA1; TestPoint_THTPad_2.5x2.5mm_Drill1.2mm
TPA2: TPA2; TestPoint_THTPad_2.5x2.5mm_Drill1.2mm
TPA3: TPA3; TestPoint_THTPad_2.5x2.5mm_Drill1.2mm
TPA4: TPA4; TestPoint_THTPad_2.5x2.5mm_Drill1.2mm
TPD0: TPD0; TestPoint_THTPad_2.5x2.5mm_Drill1.2mm
TPD1: TPD1; TestPoint_THTPad_2.5x2.5mm_Drill1.2mm
TPD2: TPD2; TestPoint_THTPad_2.5x2.5mm_Drill1.2mm
TPG0: TPGnd; TestPoint_THTPad_3.0x3.0mm_Drill1.5mm
TPP0: TPPower; TestPoint_THTPad_3.0x3.0mm_Drill1.5mm
U1: LM317_TO-220; TO-220-3_Vertical
U2: ATmega328P-P; DIP-28_W7.62mm
Y1: 16MHz; Crystal_HC49-U_Vertical

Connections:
+5V: C3.2, D1.1 (K), J4.1, J5.1, J6.1, J7.1, J8.1, J9.4, R1.1, R2.1, R6.1, R7.1, R8.1, R9.1, R10.1, TPP0.1, U1.2 (VO), U2.7 (VCC), U2.20 (AVCC)
/MISO: J1.1 (MISO), J7.2, U2.18 (PB4)
/MOSI: J1.4 (MOSI), J6.3, U2.17 (PB3)
/RESET: J1.5 (~RST), R1.2, U2.1 (~RESET/PC6)
/RX: J9.2, U2.6 (PD4)
/SCK: J1.3 (SCK), J7.3, U2.19 (PB5)
/SD_Echo: J5.2, U2.4 (PD2)
/TX: R4.1, U2.5 (PD3)
/US0_Echo: J4.3, U2.15 (PB1)
/US0_Trig: J4.2, U2.14 (PB0)
/US1_Trig: J6.2, U2.16 (PB2)
/US3_Echo: J8.3, J10.2, U2.3 (PD1)
/US3_Trig: J8.2, J10.1, U2.2 (PD0)
/col0: R6.2, RF1.1, RF2.1, RF3.1, TPA0.1, U2.23 (PC0)
/col1: R7.2, RF4.1, RF5.1, RF6.1, TPA1.1, U2.24 (PC1)
/col2: R8.2, RF7.1, RF8.1, RF9.1, TPA2.1, U2.25 (PC2)
/col3: R9.2, RF10.1, RF11.1, RF12.1, TPA3.1, U2.26 (PC3)
/col4: R10.2, RF13.1, RF14.1, RF15.1, TPA4.1, U2.27 (PC4)
/row0: Q3.2 (G), TPD0.1, U2.11 (PD5)
/row1: Q1.2 (G), TPD1.1, U2.12 (PD6)
/row2: Q2.2 (G), TPD2.1, U2.13 (PD7)
GND: C1.2, C2.1, C3.1, C4.1, C5.2, J1.6 (GND), J2.1, J4.4, J5.3, J6.4, J7.4, J8.4, J9.3, Q1.1 (S), Q2.1 (S), Q3.1 (S), R3.2, R5.2, TPG0.1, U2.8 (GND), U2.22 (GND)
unnamed: C1.1, J3.3, U1.3 (VI)
unnamed: C2.2, U2.21 (AREF)
unnamed: C4.2, U2.10 (XTAL2/PB7), Y1.1
unnamed: C5.1, U2.9 (XTAL1/PB6), Y1.2
unnamed: D1.2 (A), J1.2 (VCC)
unnamed: J2.2, J3.2
unnamed: J9.1, R4.2, R5.1
unnamed: Q1.3 (D), RF1.2, RF4.2, RF7.2, RF10.2, RF13.2
unnamed: Q2.3 (D), RF2.2, RF5.2, RF8.2, RF11.2, RF14.2
unnamed: Q3.3 (D), RF3.2, RF6.2, RF9.2, RF12.2, RF15.2
unnamed: R2.2, R3.1, U1.1 (ADJ)

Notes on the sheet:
Control
Sensor
Power

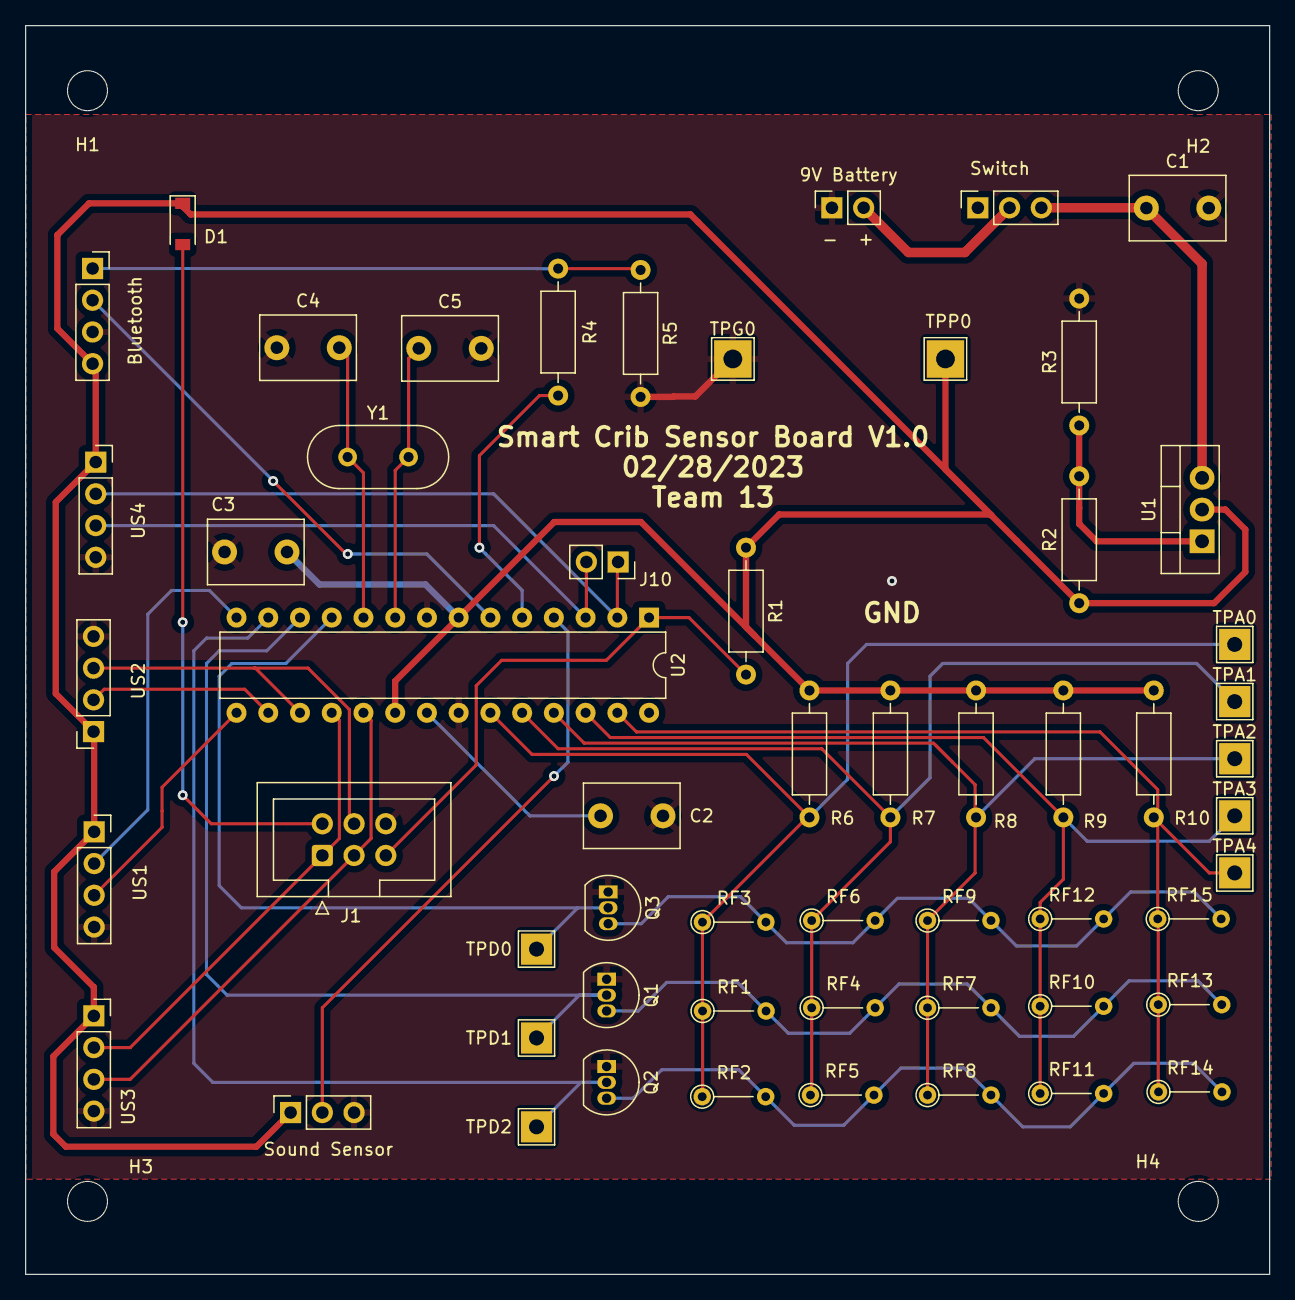
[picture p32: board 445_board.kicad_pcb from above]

Board: 2 copper layers, 99.6 x 99.9 mm, 61 parts (0 on the bottom side), 33 nets.

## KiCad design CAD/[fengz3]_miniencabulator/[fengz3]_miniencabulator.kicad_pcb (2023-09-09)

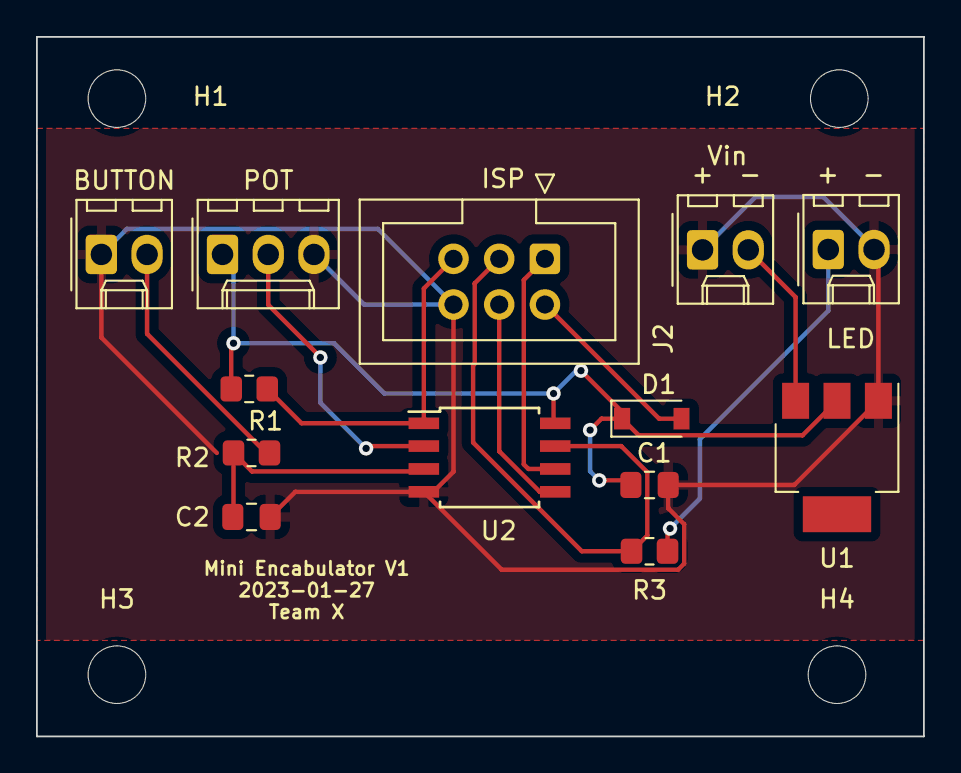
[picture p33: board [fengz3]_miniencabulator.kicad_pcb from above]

Board: 2 copper layers, 49.3 x 38.9 mm, 17 parts (0 on the bottom side), 12 nets.

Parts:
BUTTON: Button; Molex_KK-254_AE-6410-02A_1x02_P2.54mm_Vertical
C1, C2: 1uF; C_0805_2012Metric_Pad1.18x1.45mm_HandSolder
D1: MBR0520; D_SOD-123
H1, H2, H3, H4: MountingHole; MountingHole_3.2mm_M3
J2: ISP; IDC-Header_2x03_P2.54mm_Vertical
LED: LED; Molex_KK-254_AE-6410-02A_1x02_P2.54mm_Vertical
POT: POT; Molex_KK-254_AE-6410-03A_1x03_P2.54mm_Vertical
R1, R2: 10k; R_0805_2012Metric_Pad1.20x1.40mm_HandSolder
R3: 1k; R_0805_2012Metric_Pad1.20x1.40mm_HandSolder
U1: LM1117-5.0; SOT-223
U2: ATtiny85-20S; SOIC-8W_5.3x5.3mm_P1.27mm
Vin: Vin; Molex_KK-254_AE-6410-02A_1x02_P2.54mm_Vertical

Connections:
+5V: C1.1, D1.1 (K), POT.1, R1.1, U1.2 (VO), U2.8 (VCC)
/BUTTON: C2.1, R2.1, U2.3 (XTAL2/PB4)
/MISO: J2.1 (MISO), U2.6 (PB1)
/MOSI: J2.4 (MOSI), U2.5 (AREF/PB0)
/RST: J2.5 (~RST), R1.2, U2.1 (~RESET/PB5)
/SCK: J2.3 (SCK), R3.2, U2.7 (PB2)
GND: BUTTON.1, C1.2, C2.2, J2.6 (GND), LED.2, POT.3, U1.1 (GND), U2.4 (GND), Vin.1
unnamed: D1.2 (A), J2.2 (VCC)
unnamed: U1.3 (VI), Vin.2
unnamed: LED.1, R3.1
unnamed: BUTTON.2, R2.2
unnamed: POT.2, U2.2 (XTAL1/PB3)

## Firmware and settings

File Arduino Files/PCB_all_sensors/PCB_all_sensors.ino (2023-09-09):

const int trigPin0 = PIN_PB0;
const int echoPin0 = PIN_PB1;
const int trigPin1 = PIN_PB2;
const int echoPin1 = PIN_PB3;
const int trigPin2 = PIN_PB4;
const int echoPin2 = PIN_PB5;
const int trigPin3 = PIN_PD0;
const int echoPin3 = PIN_PD1;
const int PIN_ANALOG_IN = PIN_PC5;
const int PIN_GATE_IN = PIN_PD2;
const int trigPin0_p = PIN_PD5;
const int trigPin1_p = PIN_PD6;
const int trigPin2_p = PIN_PD7;
const int sensorPin0 = PIN_PC0;
const int sensorPin1 = PIN_PC1;
const int sensorPin2 = PIN_PC2;
const int sensorPin3 = PIN_PC3;
const int sensorPin4 = PIN_PC4;

const int BT_RX = PIN_PD3;
const int BT_TX = PIN_PD4;

int BTdelay = 50;
byte newstates = 0b00000000;
unsigned long lasttime = 0;
long duration, distance, Distance0, Distance1, Distance2, Distance3;
int ana_val = 0;
int gate_val = 0;
int n = 0;
int ss_sample_lasttime = 0;
int ss_sample_delay = 400;
int ss_alarm_lasttime = 0;
int ss_alarm_delay = 2000;
int ss_threshold = 150;
bool ss_alarm_remain = false;
bool hasrun = false;
int count = 0;
int ps_delay=10;
int ps_threshold = 1018;
unsigned long last_ps_time = 0;
int displacement = 0;
int dig_val[4] = {0,0,0,0};


int a[3][5] = {0};
int b[3][5] = {0};


#include <SoftwareSerial.h>
SoftwareSerial hc05(BT_TX, BT_RX);

void setup() {
  // put your setup code here, to run once:
  pinMode(trigPin0, OUTPUT);
  pinMode(echoPin0, INPUT);
  pinMode(trigPin1, OUTPUT);
  pinMode(echoPin1, INPUT);
  pinMode(trigPin2, OUTPUT);
  pinMode(echoPin2, INPUT);
  pinMode(trigPin3, OUTPUT);
  pinMode(echoPin3, INPUT);
  pinMode(PIN_ANALOG_IN, INPUT);
  pinMode(trigPin0_p, OUTPUT);
  pinMode(trigPin1_p, OUTPUT);
  pinMode(trigPin2_p, OUTPUT);
  hc05.begin(9600);
}

void loop() {
  byte states = 0b00000000;
  //Ultrasonic Sensor
  SonarSensor(trigPin0, echoPin0); //need 65
  Distance0 = distance;
  SonarSensor(trigPin1, echoPin1);  //need 65
  Distance1 = distance;
  SonarSensor(trigPin2, echoPin2);
  Distance2 = distance;  
  SonarSensor(trigPin3, echoPin3);
  Distance3 = distance;

  int arr[4] = {Distance0, Distance1, Distance2, Distance3};
  // int arr[1] = {Distance1};
  //int arr[2] = {Distance1, Distance3};
  //int arr[3] = {Distance0, Distance1, Distance3};

  for(int i = 0; i <= 3; i++){
    if(arr[i] <= 65){
      bitSet(states, 0);//set the 1st bit
      break;
    }
  }

  //Sound Sensor
  //analog version
  // ana_val = analogRead(PIN_ANALOG_IN);

  // if(ana_val >= 150){
  //   bitSet(states, 1);//set the 2nd bit
  // }
  // gate_val = digitalRead(PIN_GATE_IN);
  // if(gate_val == 1){
  //   bitSet(states, 1);//set the 2nd bit
  // }
  //-------------------------------------------------------------------
  // complicated version
  if(dig_val[0] == 1 && dig_val[1] == 1 && dig_val[2] == 1 && dig_val[3] == 1){
    bitSet(states, 1);
    //ss_alarm_remain = true;
    ss_alarm_lasttime = millis();
  }

  if(millis() >= ss_sample_lasttime + ss_sample_delay){
    for (int i = 0; i < 3; ++i) {
      dig_val[i] = dig_val[i + 1];
    }
    dig_val[3] = digitalRead(PIN_GATE_IN);
    ss_sample_lasttime = millis();
    // n++;
  }
  //-------------------------------------------------------------------

  // //  else {
  // //   ss_alarm_remain = false;
  // // }

  // if(n == 4){
  //   n = 0;
  // }  

  // if(millis() <= ss_alarm_lasttime + ss_alarm_delay){
  //   if (ss_alarm_remain == true) {
  //     bitSet(states, 1);
  //   }
  // }
  
  //Pressure Sensor
  if(hasrun == false){
    ReadPressureSensor();
    for(int i = 0; i <= 2; i++){
      for(int j = 0; j<= 4; j++){
        if(a[i][j] <= ps_threshold){
          a[i][j] = 1;
        }else{
          a[i][j] = 0;
        }
        b[i][j] = a[i][j];
        a[i][j] = 0;
      }
    }

    hasrun = true;  
  }

  for(int i = 0; i <= 9; i++){
    ReadPressureSensor(); 
  }  

for(int i = 0; i <= 2; i++){
    for(int j = 0; j<= 4; j++){
      a[i][j] = a[i][j] / 10;
      if(a[i][j] <= ps_threshold){
          a[i][j] = 1;
        }else{
          a[i][j] = 0;
        }
      //calculate the number of position change
      displacement = a[i][j]-b[i][j];
      if(displacement != 0){
        count++;
      }
    }
  }  

  if(count >= 1){
    bitSet(states, 2);
  }

  displacement = 0;
  count = 0;
  for(int i = 0; i <= 2; i++){
    for(int j = 0; j <= 4; j++){
      b[i][j] = a[i][j];
      a[i][j] = 0;
    }
  }

  if(millis() < lasttime + BTdelay){
    newstates = newstates | states;
  } else {
    hc05.write(newstates);
    newstates = newstates & 0;
    lasttime = millis();
  }
}

void SonarSensor(int trigPin, int echoPin){
  digitalWrite(trigPin, LOW);
  delayMicroseconds(2);
  digitalWrite(trigPin, HIGH);
  delayMicroseconds(10);
  digitalWrite(trigPin, LOW);
  duration = pulseIn(echoPin, HIGH);
  distance = (duration/2) / 29.1;
}
void ReadPressureSensor(){
  digitalWrite(trigPin0_p, HIGH);
  digitalWrite(trigPin1_p, LOW);
  digitalWrite(trigPin2_p, LOW);
  
  delayMicroseconds(ps_delay);      
  a[0][0]=a[0][0]+analogRead(sensorPin0);
  a[0][1]=a[0][1]+analogRead(sensorPin1);
  a[0][2]=a[0][2]+analogRead(sensorPin2);
  a[0][3]=a[0][3]+analogRead(sensorPin3);
  a[0][4]=a[0][4]+analogRead(sensorPin4);


  //second 1*5
  digitalWrite(trigPin0_p, LOW);
  digitalWrite(trigPin1_p, HIGH);
  digitalWrite(trigPin2_p, LOW);

  delayMicroseconds(ps_delay);    
  a[1][0]=a[1][0]+analogRead(sensorPin0);
  a[1][1]=a[1][1]+analogRead(sensorPin1);
  a[1][2]=a[1][2]+analogRead(sensorPin2);
  a[1][3]=a[1][3]+analogRead(sensorPin3);
  a[1][4]=a[1][4]+analogRead(sensorPin4);

  //third 1*5
  digitalWrite(trigPin0_p, LOW);
  digitalWrite(trigPin1_p, LOW);
  digitalWrite(trigPin2_p, HIGH);
  
  delayMicroseconds(ps_delay);    
  
  a[2][0]=a[2][0]+analogRead(sensorPin0);
  a[2][1]=a[2][1]+analogRead(sensorPin1);
  a[2][2]=a[2][2]+analogRead(sensorPin2);
  a[2][3]=a[2][3]+analogRead(sensorPin3);
  a[2][4]=a[2][4]+analogRead(sensorPin4);

}

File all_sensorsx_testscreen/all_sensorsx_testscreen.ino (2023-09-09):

/***************************************************
* Piezo Vibration Sensor 
* ****************************************************
* This example The sensors detect vibration

* @author linfeng(490289303@qq.com)
* @version  V1.0
* @date  2016-2-26

* GNU Lesser General Public License.
* See <http://www.gnu.org/licenses/> for details.
* All above must be included in any redistribution
* ****************************************************/
const int trigPin0 = 7;
const int echoPin0 = 8;
const int trigPin1 = 9;
const int echoPin1 = 10;
const int trigPin2 = 11;
const int echoPin2 = 12;
//const int trigPin3 = 0;
//const int echoPin3 = 1;

//long duration, distance, Distance0, Distance1, Distance2, Distance3;
long duration, distance, Distance0, Distance1, Distance2;

#define sensorPin0 A0
#define sensorPin1 A1
#define sensorPin2 A2
#define sensorPin3 A3
#define sensorPin4 A4
#define PIN_ANALOG_IN A5
#define trigPin0_p 4
#define trigPin1_p 5
#define trigPin2_p 6
#define PIN_GATE_IN 13

int a[3][5] = {0};
int b[3][5];
int count = 0;
int displacement = 0;
bool hasrun = false;
int dig_val, ana_val;
int ps_delay=10;
int ps_threshold = 1000;
byte test = 0b01000001;

int BTdelay = 100;
byte newstates = 0b00000000;
unsigned long lasttime = 0;

#include <SoftwareSerial.h>
SoftwareSerial hc05(3,2);


void setup() {
  pinMode(trigPin0, OUTPUT);
  pinMode(echoPin0, INPUT);
  pinMode(trigPin1, OUTPUT);
  pinMode(echoPin1, INPUT);
  pinMode(trigPin2, OUTPUT);
  pinMode(echoPin2, INPUT);
  //pinMode(trigPin3, OUTPUT);
  //pinMode(echoPin3, INPUT);
  pinMode(trigPin0_p, OUTPUT);
  pinMode(trigPin1_p, OUTPUT);
  pinMode(trigPin2_p, OUTPUT);
  pinMode(PIN_GATE_IN, INPUT);


  Serial.begin(9600);
  hc05.begin(9600);
  //Serial.println("Initialized");
  //delay(210);   //due to the fact that the sound sensor need some time to setup, otherwise it will output a digital 1 through gate output

}

void loop() {


  byte states = 0b00000000;

  //multiple ultrasonic sensors
  SonarSensor(trigPin0, echoPin0);
  Distance0 = distance;
  SonarSensor(trigPin1, echoPin1);
  Distance1 = distance;
  SonarSensor(trigPin2, echoPin2);
  Distance2 = distance;  
  //SonarSensor(trigPin3, echoPin3);
  //Distance3 = distance;  
  
  /*
  Serial.print(Distance0);
  Serial.print(" - ");
  Serial.print(Distance1);
  Serial.print(" - ");
  Serial.print(Distance2);
  Serial.print(" - ");
  Serial.println(Distance3);
  delay(20);
  */
  
  //int arr[4] = {Distance0, Distance1, Distance2, Distance3};
  int arr[3] = {Distance0, Distance1, Distance2};

  for(int i = 0; i <= 2; i++){
    if(arr[i] <= 50){
      bitSet(states, 0);//set the 1st bit
      //delay(100);
      //Serial.println(states);
      //delay(100);
      break;
    }
  }


  //sound sensor
  ana_val = analogRead(PIN_ANALOG_IN);
  //dig_val = digitalRead(PIN_GATE_IN);
  //Serial.println(ana_val);
  //Serial.print("Detected Voice: ");
  //Serial.println(dig_val);

  if(ana_val >= 300){
    bitSet(states, 1);//set the 2nd bit
  }

  //delay(10);





  //pressure sensor------------------------------------------------------------------------------------
  //initialize the measurement from the pressure sensor and digitalize the matrix
  if(hasrun == false){
    //Serial.print("HasRun is ");
    //Serial.println(hasrun);
    ReadPressureSensor();
    for(int i = 0; i <= 2; i++){
      for(int j = 0; j<= 4; j++){
        if(a[i][j] <= ps_threshold){
          a[i][j] = 1;
        }else{
          a[i][j] = 0;
        }
        //Serial.println(a[i][j]);
        //delay(200);
      }

    }

    hasrun = true;  
    //Serial.print("HasRun is ");
    //Serial.println(hasrun);
  }
  
  //copying the previous reading to matrix b
  for(int i = 0; i <= 2; i++){
    for(int j = 0; j <= 4; j++){
      b[i][j] = a[i][j];
    }
  }

  //get the newest measurement
  ReadPressureSensor();
  //digitalize the newest measurement
  for(int i = 0; i <= 2; i++){
    for(int j = 0; j<= 4; j++){
      if(a[i][j] <= ps_threshold){
          a[i][j] = 1;
        }else{
          a[i][j] = 0;
        }
      //Serial.println(a[i][j]);
      //delay(200);
      //calculate the number of position change
      displacement = a[i][j]-b[i][j];
      if(displacement != 0){
        count++;
      }
    }
  }  

  //Serial.print("Count is ");
  //Serial.println(count);

  //set the 3rd bit
  if(count >= 1){
    bitSet(states, 2);
  }

  displacement = 0;
  count = 0;
 
  //states += 48;

  //Serial.print("Byte is: ");
  //Serial.println(states);
  //delay(100);
  //hc05.write(states);
  //delay(1000);
/*  
  if (test + 1 > 90) {
    test = 65;
  } else {
    test = test + 1;
  }
  //delay(10);
*/
  if(millis() < lasttime + BTdelay){
    newstates = newstates | states;
  } else {
    hc05.write(newstates);
    newstates = newstates & 0;
    lasttime = millis();
    //Serial.println(newstates);
  }


}



void SonarSensor(int trigPin, int echoPin){
  digitalWrite(trigPin, LOW);
  delayMicroseconds(2);
  digitalWrite(trigPin, HIGH);
  delayMicroseconds(10);
  digitalWrite(trigPin, LOW);
  duration = pulseIn(echoPin, HIGH);
  distance = (duration/2) / 29.1;
}


void ReadPressureSensor(){
  digitalWrite(trigPin0_p, HIGH);
  digitalWrite(trigPin1_p, LOW);
  digitalWrite(trigPin2_p, LOW);
  
  delayMicroseconds(ps_delay);      
  a[0][0]=analogRead(sensorPin0);
  a[0][1]=analogRead(sensorPin1);
  a[0][2]=analogRead(sensorPin2);
  a[0][3]=analogRead(sensorPin3);
  a[0][4]=analogRead(sensorPin4);

  /*
  Serial.print("TrigPin0High: ");
  Serial.print(a[0][0]);
  Serial.print("-");
  Serial.print(a[0][1]);
  Serial.print("-");
  Serial.print(a[0][2]);
  Serial.print("-");
  Serial.print(a[0][3]);
  Serial.print("-");
  Serial.println(a[0][4]);
  */

  delayMicroseconds(ps_delay);      

  //second 1*5
  digitalWrite(trigPin0_p, LOW);
  digitalWrite(trigPin1_p, HIGH);
  digitalWrite(trigPin2_p, LOW);

  delayMicroseconds(ps_delay);    
  a[1][0]=analogRead(sensorPin0);
  a[1][1]=analogRead(sensorPin1);
  a[1][2]=analogRead(sensorPin2);
  a[1][3]=analogRead(sensorPin3);
  a[1][4]=analogRead(sensorPin4);

  /*
  Serial.print("TrigPin1High: ");
  Serial.print(a[1][0]);
  Serial.print("-");
  Serial.print(a[1][1]);
  Serial.print("-");
  Serial.print(a[1][2]);
  Serial.print("-");
  Serial.print(a[1][3]);
  Serial.print("-");
  Serial.println(a[1][4]);
  */

  delayMicroseconds(ps_delay);

  //third 1*5
  digitalWrite(trigPin0_p, LOW);
  digitalWrite(trigPin1_p, LOW);
  digitalWrite(trigPin2_p, HIGH);
  
  delayMicroseconds(ps_delay);    

  a[2][0]=analogRead(sensorPin0);
  a[2][1]=analogRead(sensorPin1);
  a[2][2]=analogRead(sensorPin2);
  a[2][3]=analogRead(sensorPin3);
  a[2][4]=analogRead(sensorPin4);

  /*
  Serial.print("TrigPin2High: ");
  Serial.print(a[2][0]);
  Serial.print("-");
  Serial.print(a[2][1]);
  Serial.print("-");
  Serial.print(a[2][2]);
  Serial.print("-");
  Serial.print(a[2][3]);
  Serial.print("-");
  Serial.println(a[2][4]);
  */
  delayMicroseconds(ps_delay); 

}
